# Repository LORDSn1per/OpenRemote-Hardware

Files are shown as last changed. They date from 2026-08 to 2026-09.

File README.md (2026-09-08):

# OpenRemote Rev6 Hardware

<p align="center">
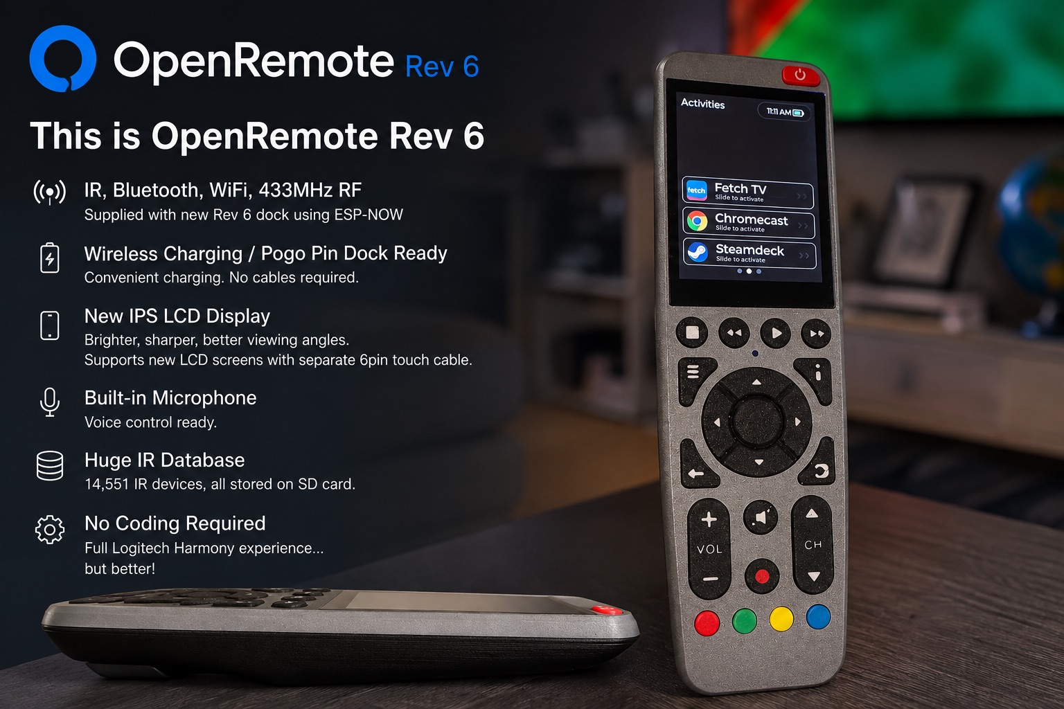
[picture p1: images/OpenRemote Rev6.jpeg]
OpenRemote Rev6 universal remote
  
</p>

OpenRemote Rev6 is an open-source, offline smart remote based on the excellent [OMOTE hardware](https://github.com/OMOTE-Community/OMOTE-Hardware). It combines a 2.8-inch capacitive touchscreen with physical buttons, infrared, Wi-Fi, Bluetooth, an ESP32-S3, expandable storage, and a fully 3D-printable enclosure.

Rev6 focuses on making the remote easier to source, nicer to print, more serviceable, and ready for dock charging—while retaining support for the original Adafruit display.

> **Firmware:** [OpenRemote Firmware](https://github.com/LORDSn1per/OpenRemote-Firmware)

## What is new in Revision 6?

- **New IPS display support.** Rev6 supports the EastRising/BuyDisplay ER-TFT028A2-4 capacitive display with a separate six-pin touch FPC. It is brighter, sharper, has much better viewing angles, is still in production, and is free of the ghost-touch problem that affected the original screen.
- **Original display compatibility.** The discontinued Adafruit Product 2770/CH280QV10-CT display remains fully supported, and the Rev6 firmware includes an option that runs it with zero ghost touches.
- **Built-in microphone.** A rear-mounted digital I2S microphone provides hardware support for voice control, voice search, and future assistant features.
- **Faster charging.** The TP4056 charging circuit is configured for up to approximately 1 A, subject to the battery, power source, and thermal conditions.
- **Dock charging input.** Rev6 includes a dedicated 5 V input before the fuse, feeding the pogo-pin charging dock contacts or any other 5 V source.
- **Improved serviceability.** Five rear-installed M3 × 8 mm screws secure the PCB and enclosure, making the remote easier to assemble and reopen.
- **Updated PCB branding.** The board is now branded OpenRemote and includes a QR code linking directly to the firmware repository.

<p align="center">
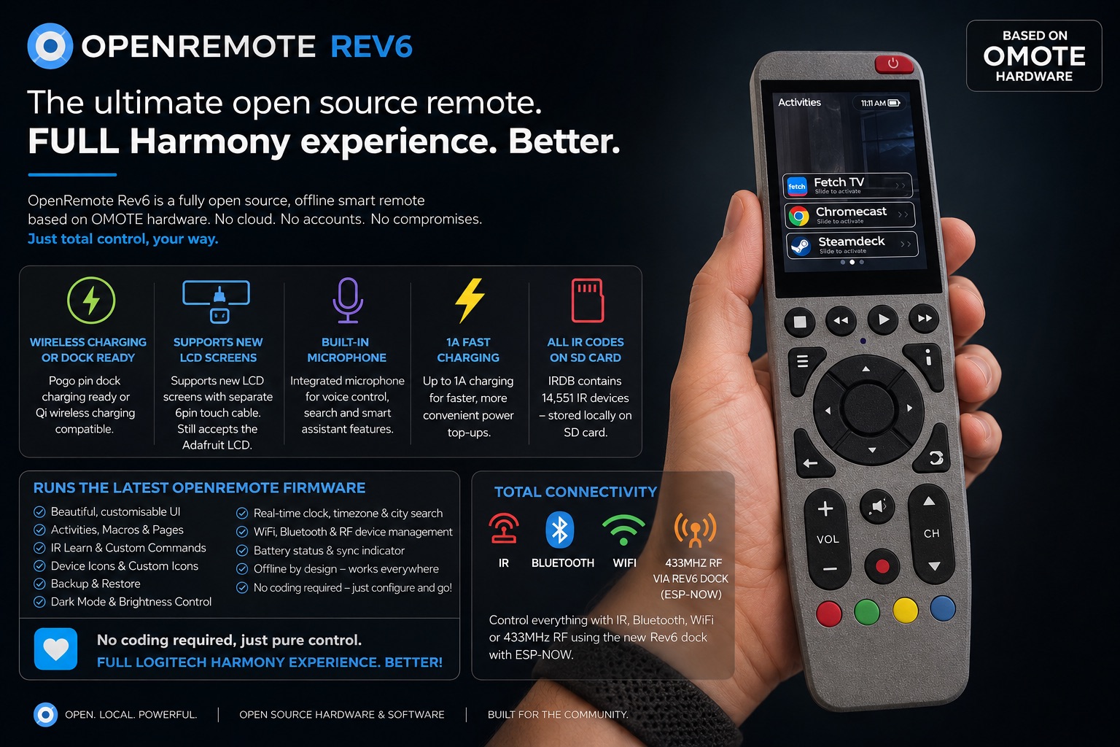
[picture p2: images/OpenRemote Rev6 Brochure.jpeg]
OpenRemote Rev6 feature overview
  
</p>

## New BuyDisplay LCD

### Why the display changed

Two things forced the move away from the original Adafruit screen:

1. **It is discontinued.** The Adafruit Product 2770 / CH280QV10-CT is no longer in production. Anyone building a remote today is hunting through dwindling stock and resellers, which is no basis for a project people are meant to be able to build.
2. **Its touch behaviour could make the remote unusable.** The Adafruit panel is subject to a well-known ghost-touch problem — phantom presses the user never made. On a remote control that is not a cosmetic annoyance: the device wakes by itself, fires commands at your equipment, and drains its own battery.

The recommended Rev6 screen is therefore the 2.8-inch 240×320 EastRising/BuyDisplay IPS TFT with capacitive touch. It is in current production, easier to source, brighter and sharper, has far better viewing angles, and does not suffer the ghost-touch fault. Its separate six-pin touch cable connects to the new J6 connector on the Rev6 PCB.

### The Adafruit display still works — with zero ghost touches

If you already own the Adafruit panel, it is not wasted. The Rev6 firmware includes an option that changes how the Adafruit touch panel is handled, and with it enabled the display produces **zero ghost touches**. It is a fully supported configuration, not a fallback, and it is why the Adafruit cover plate and matching printed parts are still published here.

Choose your display on this basis:

- **Building from scratch, or buying a screen now** — use the BuyDisplay panel. It is the current, in-production part.
- **Already have the Adafruit panel** — use it, enable the Adafruit touch option in the firmware, and print the Adafruit cover plate.

Either way, set the correct display option in the [OpenRemote firmware](https://github.com/LORDSn1per/OpenRemote-Firmware) before use.

### Fitting

The BuyDisplay assembly is approximately **0.8 mm thicker** than the original Adafruit screen. It therefore requires the newly updated BuyDisplay front cover plate. Do not try to force the thicker display into the original Adafruit cover.

Printable parts are split by display, so each folder contains a complete, matched set:

- [`CAD/BuyDisplay LCD/`](CAD/BuyDisplay%20LCD) — use **`Cover Plate 5mm (+1mm) Rev6-v37.stl`** with the new BuyDisplay screen.
- [`CAD/Adafruit LCD/`](CAD/Adafruit%20LCD) — use **`Cover Plate 4mm (+0mm) Rev6-v37.stl`** with the original Adafruit screen.

Each folder also carries a **Bambu Lab 3MF project** prepared for multicolour printing.

| BuyDisplay screen | New and original screens |
|:---:|:---:|
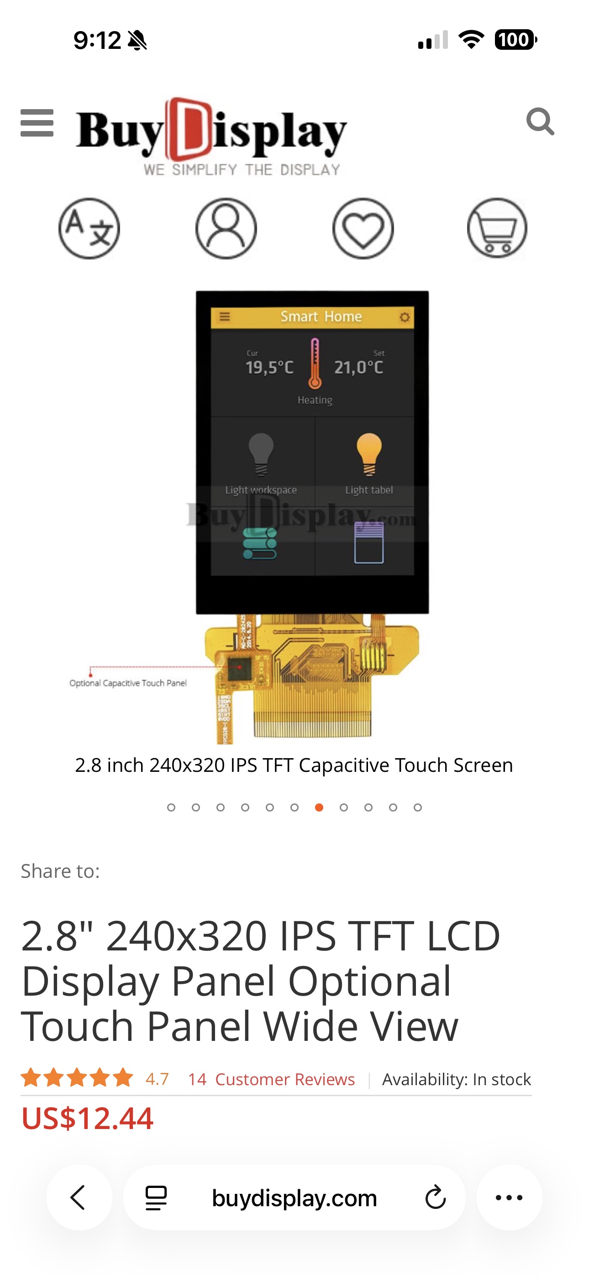
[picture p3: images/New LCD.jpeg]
BuyDisplay 2.8-inch IPS capacitive display
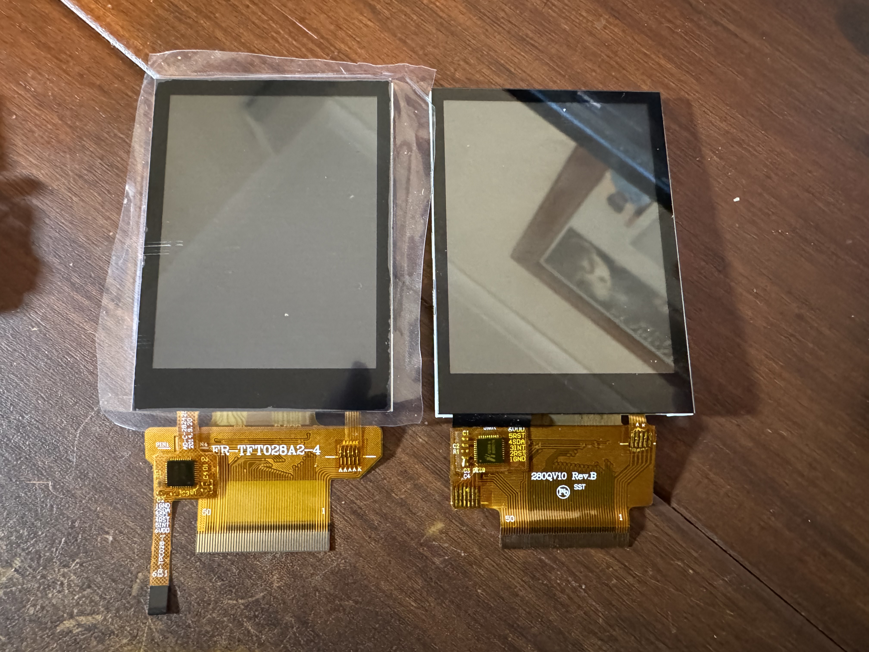
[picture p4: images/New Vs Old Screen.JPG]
BuyDisplay screen beside the original Adafruit screen
|  |  |

## Redesigned printed buttons

The Rev6 button system has been redesigned for a cleaner, more professional finish:

- The button grid now prints as **two interlocking halves** that click together.
- Separating the grid makes multicolour button graphics easier to print cleanly.
- Button faces are now completely smooth.
- The old physical cut-outs used to form button icons have been removed.
- Icons and labels can instead be printed directly into the smooth button surfaces for sharper graphics and a much nicer feel.
- The supplied Bambu Lab 3MF project contains the prepared colour-printing setup.

## Rear-case options

The Rev6 enclosure is available with two rear-shell choices:

1. **Normal rear case** — the standard shell for USB-C charging (`Case - Screws and No Pogo Pins Rev6-v37.stl`).
2. **Pogo-pin rear case** — adds two charging contacts for the self-aligning charging dock (`Case - Screws with Pogo Pins Rev6-v37.stl`).

The spring-loaded pogo pins live in the dock; the remote carries fixed gold-plated contacts, so there is nothing sprung to wear out in the handheld part.

## Charging dock

<div align="center">
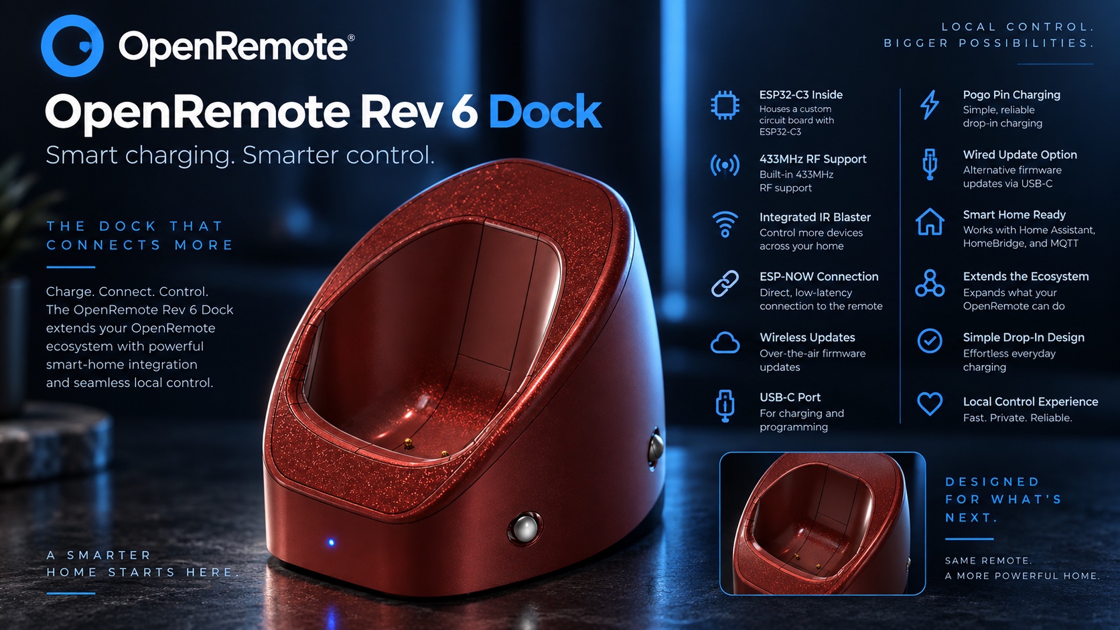
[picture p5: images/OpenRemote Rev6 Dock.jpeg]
OpenRemote Rev6 Dock feature overview
  
</div>

The Rev6 charging dock is a self-aligning cradle that charges the remote through the pogo-pin rear case, and doubles as an always-on IR and sub-GHz blaster in its own right.

- **Pogo-pin charging.** Two spring-loaded pins meet the fixed contacts in the pogo rear case, so the remote charges by being set down rather than plugged in.
- **Independent ESP32-C3.** An ESP32-C3 Super Mini gives the dock its own Wi-Fi and Bluetooth, so it can act while the remote is asleep or away from the cradle.
- **Four-emitter IR blaster.** Four MHL512IR059CRT 940 nm emitters run in parallel, each through its own 39 Ω 0.5 W resistor, switched by an FS8205A dual MOSFET. Designed for roughly 95 mA per emitter in pulsed remote-control service, giving the dock far more IR reach than the handheld unit.
- **433 MHz sub-GHz radio.** A CC1101 module on SPI adds control of RF devices that infrared cannot reach — blinds, garage doors, and similar.
- **Status LED and button.** A tactile button on GPIO3 with hardware debounce, plus a status indicator.
- **Powered by USB-C.** The dock is powered solely through the USB-C connector on the ESP32-C3 module. The 2-pin JST header (J1) is not a second power input — it carries the 5 V rail out to the pogo pins.
- **Serviceable.** A 45 × 60 mm two-layer PCB on a 37 × 52 mm M3 mounting pattern, with a separate printed base lid.
- **Smart-home relay.** Because the board has its own Wi-Fi it can hold a permanent connection to Home Assistant, an MQTT broker or Homebridge, and act on the remote's behalf while the remote sleeps. That is a firmware capability rather than a hardware one — see the [firmware repository](https://github.com/LORDSn1per/OpenRemote-Firmware) — but it is the reason the dock carries an ESP32-C3 rather than a charging circuit alone.

> **Firmware note:** the IR bank is sized for pulsed use. Firmware must not hold `IR_PWM` high continuously.

### Dock files

- Printable parts: [`CAD/Dock/STL`](CAD/Dock/STL) — dock shell, base lid, and menu button, plus a Bambu Lab 3MF project in [`CAD/Dock`](CAD/Dock).
- Fusion source: [`CAD/Charging Dock Rev6-v47.f3z`](CAD/Charging%20Dock%20Rev6-v47.f3z)
- KiCad source: [`PCB/Dock Rev6`](PCB/Dock%20Rev6) — includes its own [project README](PCB/Dock%20Rev6/README.md) covering footprints, sourcing notes, and the Fusion handoff transform.

> **Fabrication files withdrawn.** The dock's gerbers, CPL and BOM have been removed. The ESP32-C3 Super Mini footprint on the dock PCB is wrong — the 3D model is correct, but the land pattern is not — so any board made from those files would not accept the module. **Do not order a dock PCB yet.** A corrected set will be published once the footprint is fixed and the board re-verified.

## PCB files

The complete KiCad source is in [`PCB/Revision 6`](PCB/Revision%206). Custom symbols, footprints, and 3D models are included with the project.

The exact production files prepared for the Rev6 manufacturing order are here:

- [Gerber and drill ZIP](PCB/Revision%206/PCB%20Production%20Files/gerber.zip)
- [Component placement list (CPL)](PCB/Revision%206/PCB%20Production%20Files/CPL.csv)
- [Bill of materials (BOM)](PCB/Revision%206/PCB%20Production%20Files/BOM.xlsx)

The PCB is a two-layer design. The production set was exported using the **EastRising Capacitive LCD** assembly variant. The original Adafruit display remains represented in the KiCad project as an alternate variant.

> MIC1, the microphone module, does not currently have a JLCPCB/LCSC placement code in the production BOM. Source and fit it separately if your assembler cannot supply it.

## Core hardware features

- ESP32-S3 with Wi-Fi and Bluetooth
- 2.8-inch 240×320 capacitive touchscreen
- Physical navigation, media, volume, channel, activity, and colour buttons
- High-power infrared output
- MicroSD storage
- Motion-based wake support
- Built-in I2S microphone
- USB-C charging
- Pogo-pin dock charging
- Fully local operation with no mandatory cloud service

## Building the remote

1. Order the Rev6 PCB using the supplied Gerber ZIP, BOM, and CPL.
2. Source the selected LCD and use its matching front cover plate.
3. Print the enclosure and buttons. For multicolour printing, use the supplied Bambu Lab 3MF project.
4. Fit a suitable protected 3.7 V LiPo battery with the correct JST polarity.
5. Install the PCB and secure the assembly using five M3 × 8 mm screws.
6. Flash the latest [OpenRemote firmware](https://github.com/LORDSn1per/OpenRemote-Firmware).

Always verify component orientation, battery polarity, display selection, and the manufacturer preview before ordering assembled PCBs.

## Project status

The Rev6 remote PCB has been manufactured and assembled, and the first unit is running. The normal and pogo-pin rear cases and both display cover plates are complete and published.

The charging dock's enclosure parts are complete and published. Its PCB is **not ready to order**: the ESP32-C3 Super Mini footprint is being corrected, and the fabrication files have been withdrawn until that is done and verified. The KiCad source stays published so the design can be followed and reviewed.

## Credits

OpenRemote builds on the original open-source [OMOTE](https://github.com/OMOTE-Community) hardware project. Thank you to the OMOTE contributors and community for creating the foundation that made OpenRemote possible.

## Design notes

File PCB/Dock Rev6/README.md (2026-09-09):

# OpenRemote Dock Rev6 KiCad Project

This is a self-contained KiCad 10 project starter for the OpenRemote Rev6 charging dock.

## Included footprints and 3D models

| Library footprint | Intended hardware | Interface / package |
|---|---|---|
| `ESP32-C3_SuperMini_Header_2x08_P2.54mm` | ESP32-C3 Super Mini shown by the owner | Two 1x8 headers, 2.54 mm pitch; owner-supplied STEP model |
| `CC1101_433MHz_Coil_Module_2x04_P2.54mm` | 28x15 mm CC1101 433 MHz module, spring antenna version | 2x4 header, 2.54 mm pitch |
| `LED_5mm_Side_Mount_C405273` | Meihua MHL512IR059CRT IR LED, LCSC C405273 | THT, 5 mm, horizontal/side mounting |
| `FS8205A_SOT-23-6` | FUXINSEMI FS8205A, LCSC C908265 | SOT-23-6 |
| `HX-XH2.54-2PZZ_C42391660` | hanxia HX-XH2.54-2PZZ, LCSC C42391660 | Vertical shrouded 1x2 male header; vendor land pattern is 2.50 mm pitch |
| `SW_6x6x5H_THT` | 6x6 mm tactile switch, 5 mm body height | Four-pin THT |
| `LED_5mm_Green_THT` | Standard green 5 mm LED | THT, 2.54 mm pitch |

The ESP32 model is the owner's supplied `esp32 c3 supermini.step`, copied into the project as `ESP32-C3_SuperMini.step`. The project also includes `ESP32-C3_SuperMini_2x08_Header.step`: two 2.24 mm-high black 1x8 header blocks with 16 gold pins. All STEP files are project-local, so no Downloads or global KiCad 3D-model path is required.

## Important sourcing notes

- The ESP module follows the owner's supplied **16-pin ESP32-C3 Super Mini** image: 18x22.52 mm with two 1x8, 2.54 mm header rows. It does not use the different 18-pin Waveshare C3-Zero footprint from the earlier retail link.
- J1 is the exact hanxia HX-XH2.54-2PZZ sold as LCSC C42391660. LCSC describes it as 2.54 mm, but its manufacturer-linked EasyEDA land pattern uses 2.50 mm pad pitch, 1.0 mm drills, and a 7.5 x 5.9 mm shrouded body; the project follows that land pattern.
- CC1101 clone modules vary. This footprint follows the common 28x15 mm, 2x4 2.54 mm module and the pin order shown in the provided image. Check the delivered module before ordering the PCB.
- `Dock Rev6.kicad_pcb` uses a 45x60 mm main body with narrow front and rear tongues. The confirmed physical rear tongue ends at dock Z=`-68.0 mm`; it is straight between the two rear receivers and has no obsolete scallops.
- The owner confirmed that the provisional handoff reversed the physical faces. The installed-board mapping is now **physical dock Z = KiCad Y - 140 mm**: Fusion Z=`-70` is the rear and Z=`+30` is the front.
- U1 is centred at KiCad `(100.00, 82.39)` with USB-C facing the physical rear and is placed on `B.Cu`. The ESP32 module hangs below the host PCB; the black header plastic lies between the ESP32 board and the host PCB, as it will when assembled with female header sockets. It was moved 1.5 mm into the cavity so the module PCB clears the rear wall. Its exact 18 mm body has approximately 0.50 mm lateral clearance to each physical rear lid receiver.
- The four large `User.Drawings` circles are the exact **15 mm OD physical receiver outlines**, mirrored into the confirmed board coordinates. Rear centres are KiCad `(82.998, 80.858)` and `(117.002, 80.858)`; front centres are `(83.643, 161.292)` and `(116.357, 161.292)`.
- In Fusion, `Dock + Correct Rear USB-C Opening Base Feature` was removed and the retained master body was restored as the visible solid `Dock - User Editable Shell (No Cutouts)`. This leaves the enclosure apertures for the owner to sketch and cut directly without deleting the dock shell.
- The final exact-solid Fusion audit reports **no collision between the underside ESP32/header assembly and the base lid or its bosses**. The lowest point of the ESP32 model is 0.294 mm above the flat lid surface. The USB, button, and LED apertures are intentionally left for the owner to create before enclosure release.
- Four 3.3 mm NPTH M3 mounting holes are on an exact 37x52 mm pattern at dock X/Z `(+/-18.5, +6)` and `(+/-18.5, -46)`. Each hole has an R4 mm all-copper keepout. H1-H4 are locked `board_only` footprints, excluded from BOM and position files, so **Update PCB from Schematic will not delete them again**.
- The matching Fusion base lid has four 7.5 mm OD bosses at those same centres. Each boss has a 2.55 mm blind pilot, an 8.0 mm PCB seating plane, and 3.4 mm thread engagement for an M3x5 screw through this 1.6 mm board. The original pre-boss lid body is retained hidden for rollback.

## Pin order

CC1101 pads are numbered by rows as shown in the supplied diagram: `1 GND`, `2 VCC`, `3 GDO0`, `4 CSN`, `5 SCK`, `6 MOSI`, `7 MISO/GDO1`, `8 GDO2`.

ESP32-C3 Super Mini pad numbers use the printed signal names directly. USB-C is at the top: left row `5V`, `GND`, `3V3`, `GPIO4/SCK/A4`, `GPIO3/A3`, `GPIO2/A2`, `GPIO1/A1`, `GPIO0/A0`; right row `GPIO5/MISO/A5`, `GPIO6/MOSI`, `GPIO7/SS`, `GPIO8/SDA`, `GPIO9/SCL`, `GPIO10`, `GPIO20/RX`, `GPIO21/TX`.

## Electrical design

- CC1101 SPI: `GPIO4 SCK`, `GPIO5 MISO`, `GPIO6 MOSI`, `GPIO7 CSN`; interrupts are `GPIO10 GDO0` and `GPIO20 GDO2`.
- Four MHL512IR059CRT emitters are connected in parallel through individual `39R 0.5W` resistors. GPIO0 drives both paralleled halves of Q1 through `100R`, with a `100k` gate pulldown.
- The 39R IR branches are designed for pulsed remote-control service at approximately 95mA per LED from 5V. Firmware must not hold `IR_PWM` high continuously.
- The green status LED uses GPIO1 and `1k`. The tactile button uses GPIO3 with a `10k` pull-up and `100nF` hardware debounce.
- ESP32-C3 strap pins GPIO2, GPIO8, and GPIO9 are deliberately left unconnected; GPIO21 is also reserved.
- Added decoupling: `100nF + 10uF` at the ESP 5V input, `100nF + 10uF` at the CC1101 3.3V rail, and `100uF + 100nF` at the pulsed IR bank.

### Pogo-pin output protection

`F1` is a 1 A resettable polyfuse (PPTC, LCSC C220146,
`DockRev6:Fuse_1206_3216Metric_Pad1.42x1.75mm_HandSolder`) in series between the `+5V`
rail and `J1` pin 1, creating the `POGO_5V` net. It is the same part the remote uses as
its F1. The IR bank, the ESP32 and the decoupling all stay on the raw `+5V` rail; only
the pogo output passes through the fuse.

**It is in the schematic only — it is not yet placed or routed on the PCB.**

This replaced an earlier BAT20J series diode, for two reasons. A polyfuse actually
addresses the failure being guarded against: if the exposed pogo contacts are shorted,
it heats and trips, where a series diode would simply conduct and let the rail collapse.
And it barely drops any voltage — a few tens of millivolts against roughly 0.45 V for a
Schottky at 1 A — so the remote still sees close to a full 5 V.

Two things to be aware of:

- A polyfuse does **not** block reverse current. The dropped diode would have stopped
  the remote back-feeding into the dock; the fuse does not. If back-feed matters, an
  ideal-diode controller or a load switch would cover both cases.
- Trip is thermal, so it takes seconds rather than being instant, and hold current
  derates as temperature rises. With the remote's TP4056 set near 1 A, a 1 A hold part
  sits close to its limit inside a closed enclosure. Watch for nuisance trips during a
  full-rate charge; a 1.1 A or 1.5 A hold part is the fallback.

### Capacitor placement

- `C1 100nF`: immediately beside U1's 5V/GND header pins; shortest possible loop.
- `C2 10uF`: beside U1 and C1 on the 5V rail; C1 should be closer than C2.
- `C3 100nF`: immediately beside U2 pins 2 VCC and 1 GND; this is the most placement-sensitive radio capacitor.
- `C4 10uF`: beside U2 and C3; C3 should be closer than C4.
- `C5 100nF`: beside U1 GPIO3 and pull-up R1, at the controller end of the BUTTON trace.
- `C6 100uF`: beside Q1/J1 at the high-current IR power entry/current loop.
- `C7 100nF`: beside Q1/J1 and C6, with the shortest 5V-to-GND loop; C7 should be closer to the switching loop than C6.

`Dock Rev6.kicad_pcb` is populated but not routed. The remaining SMD parts are staged by circuit: C1/C2 beside the header-mounted ESP32, C5/R1 immediately left of it, C3/C4 beside the CC1101 power pins, R3/R4/Q1 to the left of the CC1101 coil envelope, C7 beside J1, and R2 beside D5. The current DRC reports silkscreen cleanup warnings plus the expected unrouted nets; it does not report a copper short, hole, or board-edge clearance failure.

The `.before-*` rollback boards, the DRC/ERC reports, the netlist and the exported schematic PDF have been removed; only the current `Dock Rev6.kicad_pcb` and `Dock Rev6.kicad_sch` are kept. Earlier states remain in git history if a rollback is ever needed. `apply_mechanical_fit_v3.py` reapplies the final U1 position and rear-tongue geometry without altering nets or component identities. Use KiCad's native refill after running it. Do not run `generate_dock_rev6_mechanical_board.py` on the populated board; that generator creates a blank mechanical PCB and would replace component placement.

## Fusion 3D handoff

`Dock Rev6 PCB Assembly.step` is the current board-plus-components model handed to
Fusion. Regenerate it with `export_dock_rev6_step.py`, which runs:

```
kicad-cli pcb export step --subst-models --no-dnp --force
```

No origin flag is passed, so the STEP keeps KiCad's absolute board coordinates
(substrate spans X `77.5`-`122.5`, Y `-166.0`-`-72.0`, Z `0`-`1.6`). The Fusion
placement transform depends on that:

```
dock X =  step X - 100 mm
dock Y =  step Z + 8 mm      (PCB seating plane on the base-lid bosses)
dock Z = -step Y - 140 mm    (owner-confirmed mirrored physical face)
```

`CAD/FusionScripts/DockRev6PCBReplace` deletes any existing `Dock Rev6 PCB*`
occurrence, re-imports this STEP at that transform as the component
`Dock Rev6 PCB`, then re-runs the solid interference check against `Dock:1` and
`Dock Base Lid:1` and writes `CAD/Dock Rev6/Charging Dock Rev6 PCB Replace Report.json`.
Base-lid interference is a failure; dock-shell interference at SW1, J1, D1-D5 is
expected until the owner cuts the USB, button, and LED apertures.

`Dock Rev6 Component Staging.step` is the superseded 26 Aug 16:52 export, taken
before power/ground routing was finalised and before SW1 moved to the
`SW-TH_KH-6X6X5H-ZJ` (C2837541) model and J1 to `HX-XH2.54-2PZZ` (C42391660). It
is kept only for rollback; Fusion should no longer import it.

`Dock Rev6 PCB Assembly Preview.png` and `Dock Rev6 PCB Assembly Preview Bottom.png`
are `kicad-cli pcb render` views of the same board state.

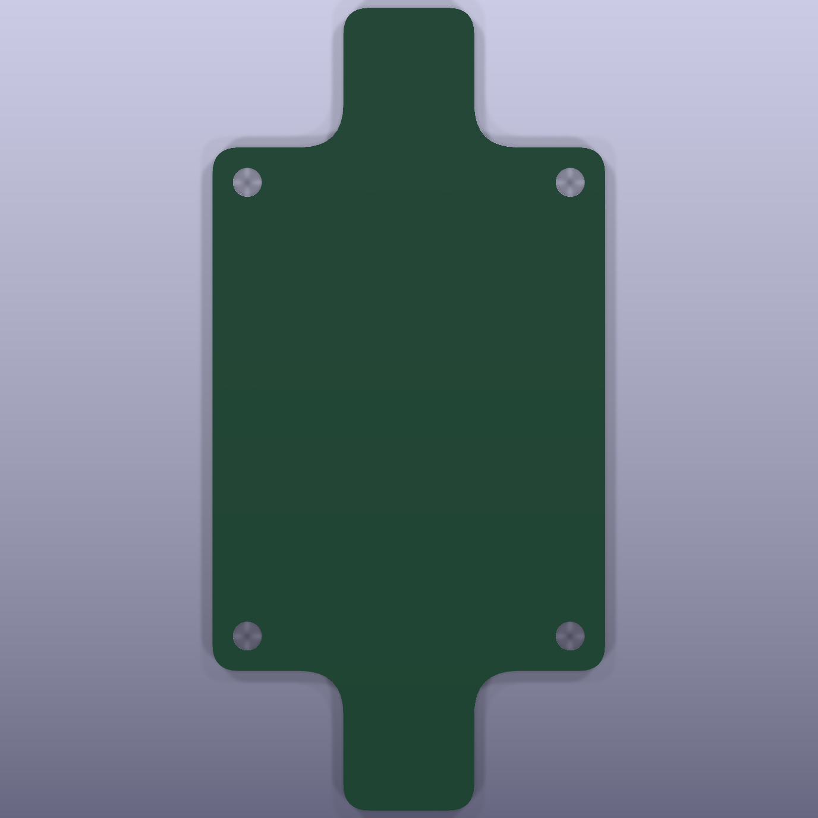
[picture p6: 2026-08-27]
PCB/Dock Rev6/Dock Rev6 PCB Mechanical Preview.png

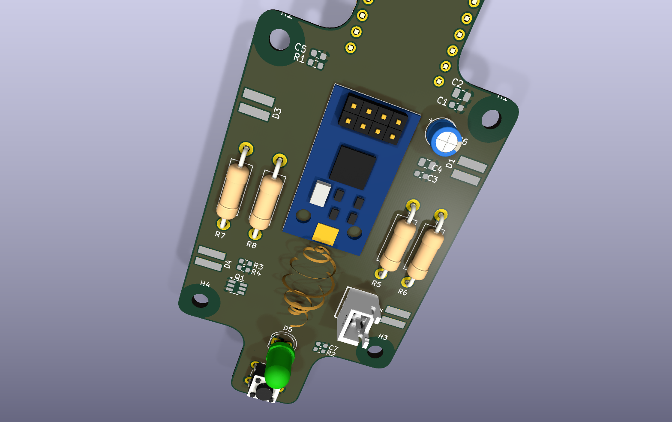
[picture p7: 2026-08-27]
PCB/Dock Rev6/Dock Rev6 J1 C42391660 Preview.png

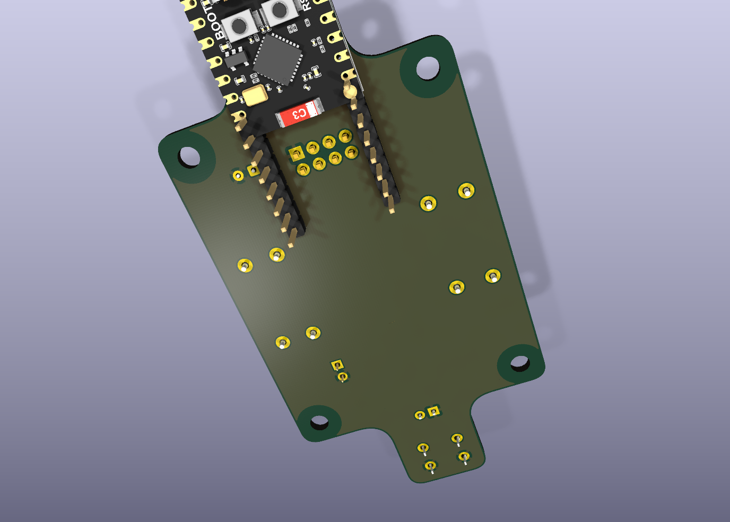
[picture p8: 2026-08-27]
PCB/Dock Rev6/Dock Rev6 Bottom ESP32 Preview.png

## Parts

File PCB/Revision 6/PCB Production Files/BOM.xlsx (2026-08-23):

Designator | Value | Footprint | LCSC Part #
C1,C9,C10,C12,C17,C20,C22,C23,C24,C26,C29 | 100nF | C_0603_1608Metric | C1591
C2,C4,C15 | 1uF | C_0603_1608Metric | C15849
C3,C5,C6,C7,C8,C11,C13,C16,C18,C21,C25,C28 | 10uF | C_0805_2012Metric | C15850
D1 | BAT20J | D_SOD-323 | C49238173
D2 | SFH4547 | LED_5mm_Side_Mount | C405273
D3,D4,D5 | LED | LED_0603_1608Metric | C965807
D6,D7,D8,D9,D10,D11,D12,D13,D14,D15,D16 | LED | LED_0603_1608Metric | C84265
F1 | 1000mA | Fuse_1206_3216Metric_Pad1.42x1.75mm_HandSolder | C220146
J1 | USB_C_Receptacle_USB2.0 | USB_C_Receptacle_HRO_TYPE-C-31-M-12 | C2982555
J2 | Conn_01x50 | TFT_2.83IN_240X320_50PIN | C11098
J3,J7 | JST_PH_B2B-PH | JST_PH_B2B-PH-SM4-TB_1x02-1MP_P2.00mm_Vertical | C160352
J5 | Micro_SD_Card | MicroSD Slot TF-01A | C20613191
J6 | ER-CON06HB-1_TOUCH | ER-CON06HB-1_Compatible_1x06_P0.50mm_BottomContact | C202118
Q1,Q3,Q4,Q5,Q7 | DMG2301L | SOT-23 | C102619
Q2 | MBT3904DW1 | SOT-363_SC-70-6 | C110150
Q6 | FS8205A | SOT-23-6 | C908265
R1,R5,R23,R31,R32,R33,R34,R35,R38,R39,R40,R41,R42,R43,R44 | 2k2 | R_0603_1608Metric | C114662
R2,R3,R27,R28,R29 | 1k | R_0603_1608Metric | C22548
R4 | 100 | R_0603_1608Metric | C125923
R6,R10,R13,R14,R19,R20,R22,R24,R25,R26,R30,R36,R37 | 10k | R_0603_1608Metric | C98220
R7,R9 | 5.1k | R_0603_1608Metric | C105580
R8 | 1K2 | R_0603_1608Metric | C22765
R11,R12 | 4k7 | R_0603_1608Metric | C99782
R15,R16,R17,R18 | 10 | R_0603_1608Metric | C109318
R21 | 3R3 | R_0805_2012Metric | C313912
R45,R46,R47 | 4k7 | R_0603_1608Metric | C23162
S1,S2,S3,S4,S5,S6,S7,S8,S9,S10,S11,S12,S13,S14,S15,S16,S17,S18,S19,S20,S22,S23,S24,S25,S26 | TL3342F160QG | SW_SPST_TL3342 | C778172
U1 | DW01A | SOT-23-6 | C18164398
U2 | XC6220B331 | SOT-23-5 | C86534
U3 | CH340C | SOIC-16_3.9x9.9mm_P1.27mm | C84681
U4 | USBLC6-2P6 | SOT-666 | C2827693
U5 | LIS3DHTR | XDCR_LIS3DHTR | C15134
U6 | TSSP77038 | Heimdall vertical | C3291489
U7 | ESP32-S3-WROOM-1-N16R8 | ESP32-S3-WROOM-1 | C2913202
U8 | AP2112K-3.3 | SOT-23-5 | C51118
U9 | MAX17048G | TDFN-8-1EP_2x2mm_P0.5mm_EP0.8x1.2mm | C2682616
U11 | TP4056 | Infineon_PG-DSO-8-27_3.9x4.9mm_EP2.65x3mm | C725790
U12 | TCA8418 | HVQFN-24-1EP_4x4mm_P0.5mm_EP2.5x2.5mm | C138713

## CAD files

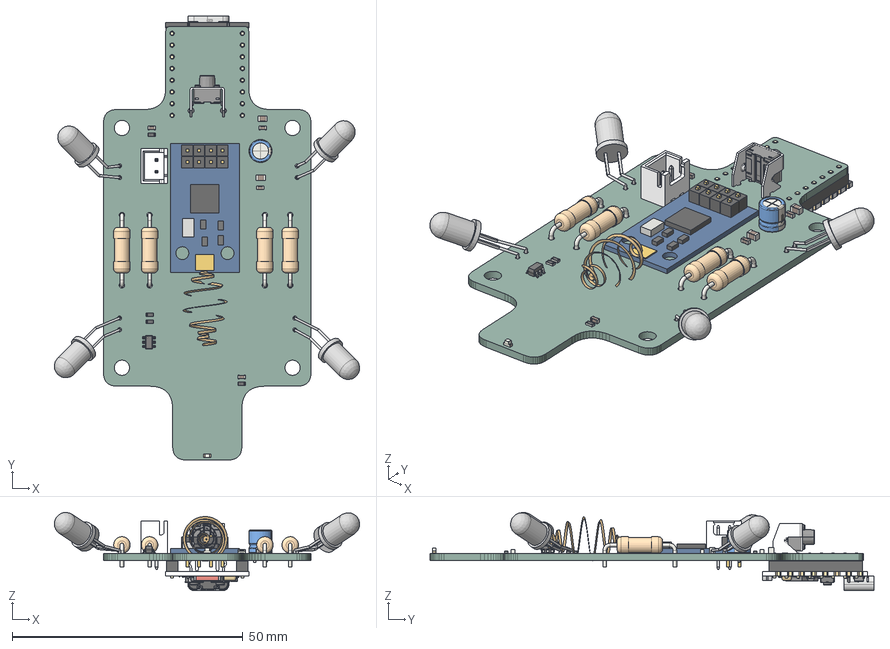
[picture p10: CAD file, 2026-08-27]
PCB/Dock Rev6/Dock Rev6 PCB Assembly.step
66.2 x 96.3 x 16.9 mm
R_Axial_DIN0411_L99mm_D36mm_P1524mm_Horizontal x 4
R_0603_1608Metric x 4
C_0603_1608Metric x 4
SOT-23-6
LED_0603_1608Metric
KiCad IR LED Assembly - 25deg 3mm
C_0805_2012Metric x 2
CP_Radial_D50mm_P250mm
CONN-TH_2P-P2.50_HX-2.54MM-2P-ZZ-MS
PCB
CC1101
Crystal
RF component 0
RF component 1
RF component 2
RF component 3
Header pin 0 -1.27
Header body 0 -1.27
Header pin 0 1.27
Header body 0 1.27
Header pin 1 -1.27
Header body 1 -1.27
Header pin 1 1.27
Header body 1 1.27
Header pin 2 -1.27
Header body 2 -1.27
Header pin 2 1.27
Header body 2 1.27
Header pin 3 -1.27
Header body 3 -1.27
Header pin 3 1.27
Header body 3 1.27
Antenna pad
433MHz spring antenna
usb4215-03-a_1
RES0201 v1 x 11
C0201 v4 x 10
C0402 v1 x 4
Cathode
Anode
Cathode Bar
QFN-32 V6 v2
switch 3x4x2mm - 2 Pad v2 x 2
TEMP ESP32-C3 2x08 Header Export
Dock Rev6_PCB

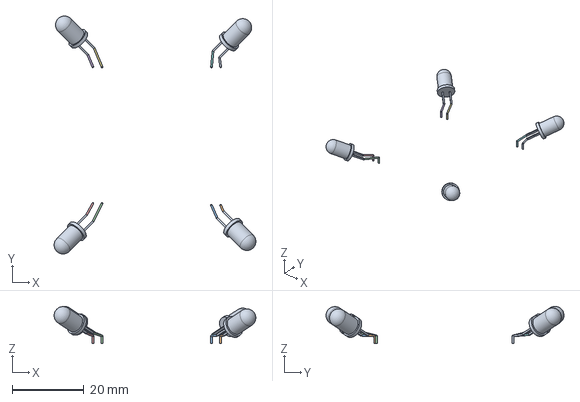
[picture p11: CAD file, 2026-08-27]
PCB/Dock Rev6/project_libraries/3D-models/Dock_IR_LED_Assembly_25deg_3mm.step
56.1 x 66.2 x 10.4 mm

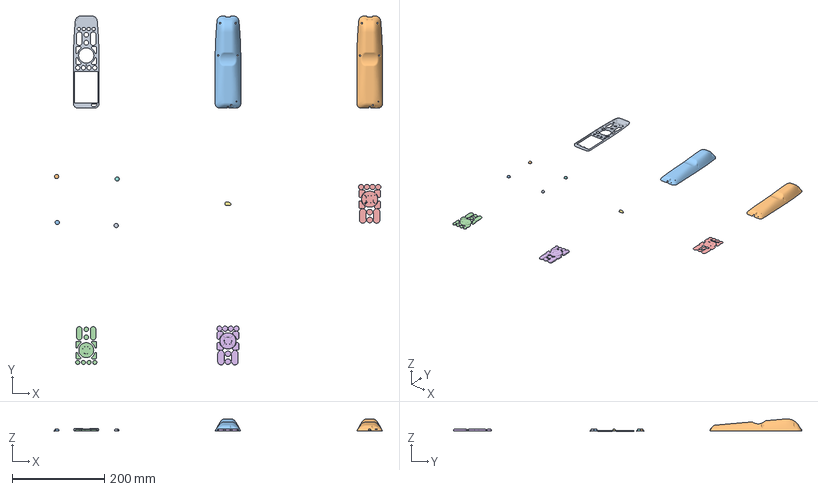
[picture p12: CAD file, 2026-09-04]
CAD/Adafruit LCD/OpenRemote Rev6 - Adafruit LCD.3mf
711.3 x 756.5 x 26.5 mm
Cover Plate 4mm (+0mm) Rev6-v37.stl
Case - Screws with Pogo Pins Rev6 v40.stl
Case - Screws and No Pogo Pins Rev6 v40.stl
Button Grid Adafruit Rev6-v37.stl_A
Button Grid Adafruit Rev6-v37.stl_B
Button Grid Adafruit Rev6-v37.stl
Off Button Adafruit Rev6-v37.stl
Colour Button Adafruit Rev6-v37.stl x 4

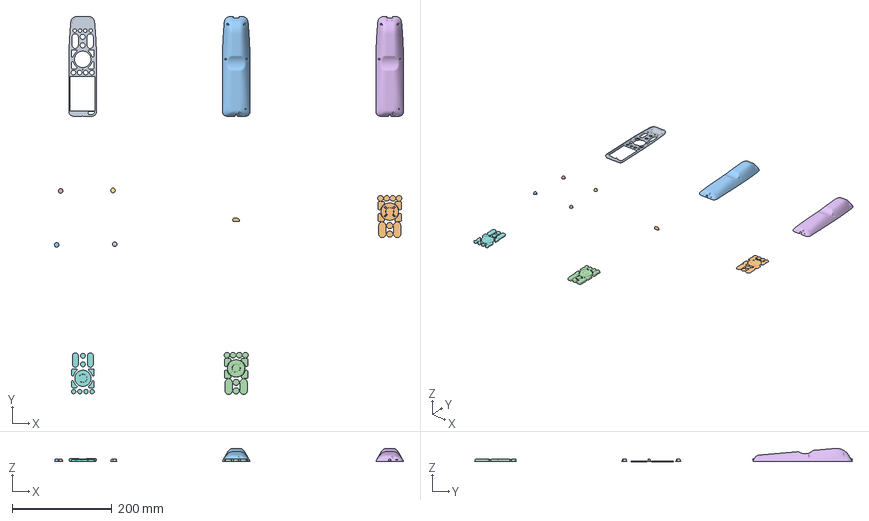
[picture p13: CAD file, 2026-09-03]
CAD/BuyDisplay LCD/OpenRemote Rev6 - BuyDisplay LCD.3mf
699.0 x 756.5 x 26.5 mm
Cover Plate 5mm (+1mm) Rev6-v37.stl
Off Button BuyDisplay Rev6-v37.stl
Colour Button BuyDisplay Rev6-v37.stl x 4
Button Grid BuyDisplay Rev6-v37.stl
Case - Screws with Pogo Pins Rev6-v37.stl
Button Grid - Flat.stl_A
Button Grid - Flat.stl_B
Case - Screws and No Pogo Pins Rev6-v37.stl

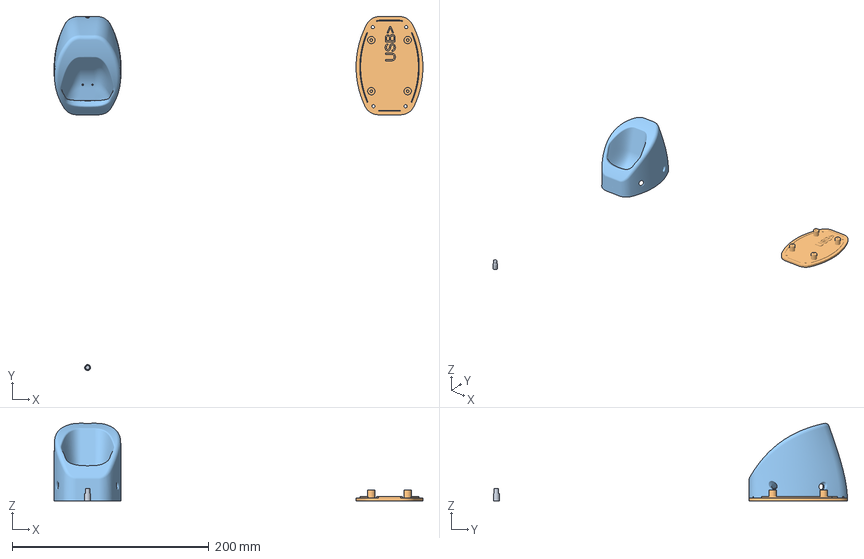
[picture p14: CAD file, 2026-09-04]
CAD/Dock/OpenRemote Dock Rev6.3mf
375.3 x 360.2 x 78.9 mm
Dock Menu Button Rev6-v47.stl
Dock Base Lid Rev6 v51.stl
Dock Rev6 v51.stl

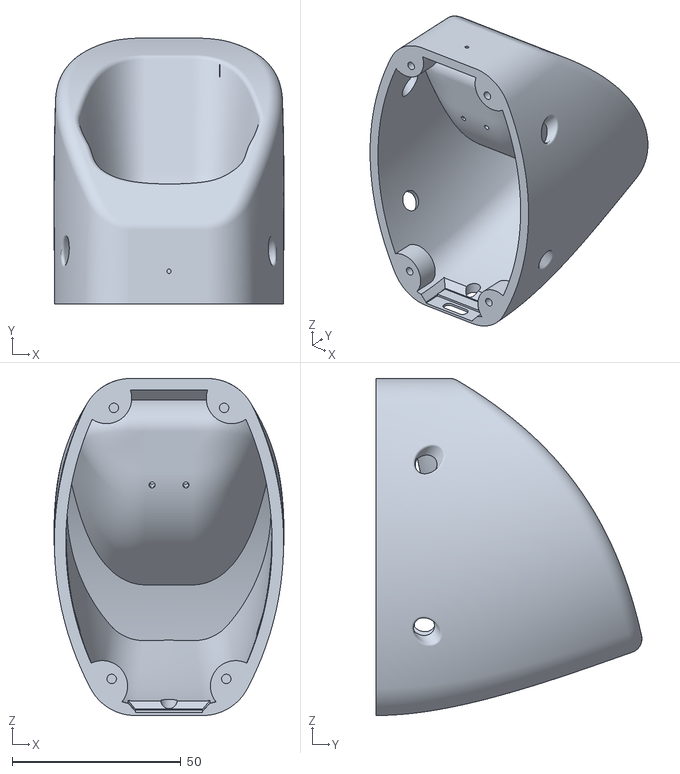
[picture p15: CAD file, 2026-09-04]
CAD/Dock/STL/Dock Rev6 v51.stl
68.2 x 78.9 x 100.0

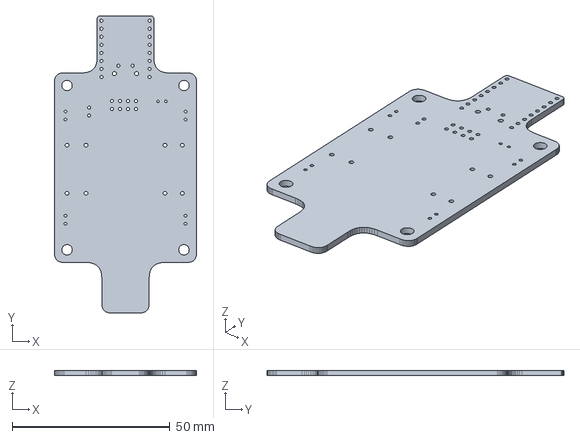
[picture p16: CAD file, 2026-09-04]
CAD/Hardware Models/Dock Rev6 PCB - Board Only.step
45.0 x 94.0 x 1.60 mm

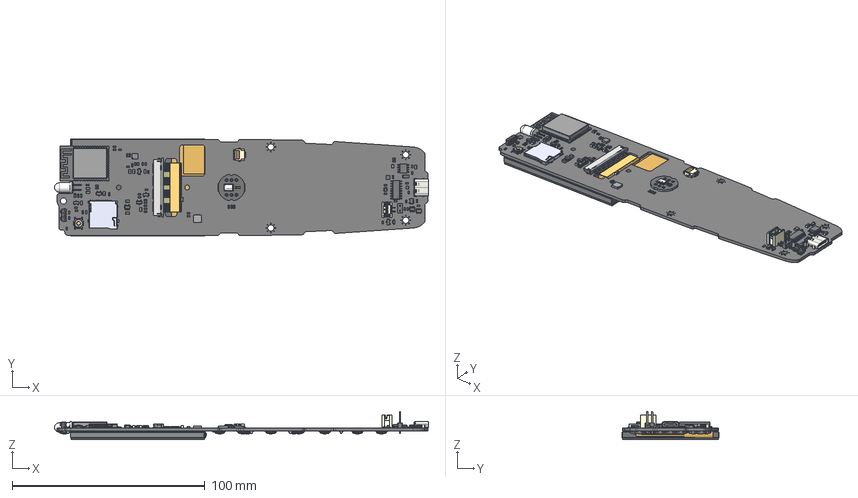
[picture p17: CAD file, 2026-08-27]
CAD/PCB Imports/OpenRemote Rev6 PCB.step
194.0 x 50.2 x 14.5 mm
Side Mount LED v1
R_0603_1608Metric x 46
D_SOD-323
B2B-PH-SM4-TB(LF)(SN)
PowerIntegrations_SO-8
C_0603_1608Metric x 15
SOT-23-5 x 2
C_0805_2012Metric x 13
SOT-23 x 6
LIS3DH
LED_0603_1608Metric x 14
SOT-363_SC-70-6
0603 Resistor v1
ESP32-S3-WROOM-1
Fuse_1206_3216Metric
SOT-23-6 x 2
(Nicht gespeichert)
SOIC-16_3.9x9.9mm_P1.27mm
(Unsaved)
DFN-8_2x2mm_Pitch0.5mm
TF-01A_TF-01A
SOT_666
PinHeader_1x02_P254mm_Vertical
lock
pins
280QV10 v5
HVQFN_24_1EP_4x4mm_P05mm_EP21x21mm
SW_SPST_TL3342 x 25
R_0805_2012Metric
USB_C_Receptacle_16P_TopMnt_Horizontal_GCT_USB4105-xx-A
display_front_00_part
display_front_01_part
display_front_02_part
display_front_03_part
display_front_04_part
display_front_05_part
display_front_06_part
display_front_07_part
screen_label_0_0_1_part
screen_label_0_0_2_part
screen_label_0_0_3_part
screen_label_0_1_0_part
screen_label_0_2_0_part
screen_label_0_3_1_part
screen_label_0_3_2_part
screen_label_0_3_3_part
screen_label_0_4_4_part
screen_label_0_5_4_part
screen_label_0_6_0_part
screen_label_0_6_1_part
screen_label_0_6_2_part
screen_label_0_6_3_part
screen_label_1_0_1_part
screen_label_1_0_2_part
screen_label_1_0_3_part
screen_label_1_0_4_part
screen_label_1_1_0_part
screen_label_1_2_0_part
screen_label_1_3_0_part
screen_label_1_4_0_part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

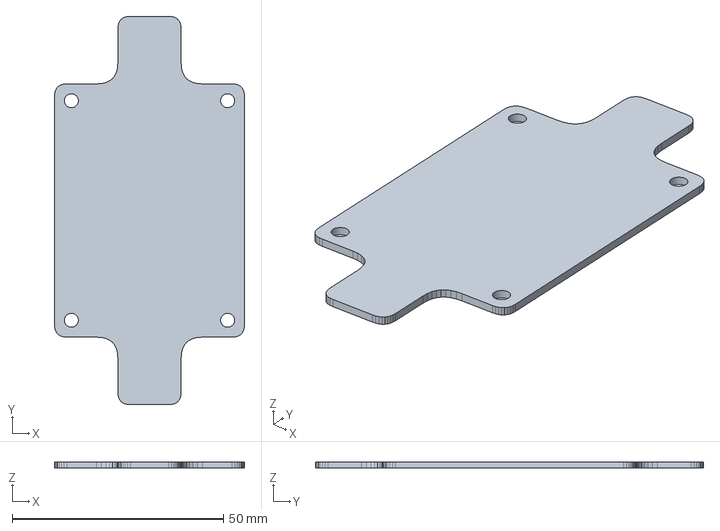
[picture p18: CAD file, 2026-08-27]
PCB/Dock Rev6/Dock Rev6 Mechanical PCB.step
45.0 x 92.0 x 1.51 mm

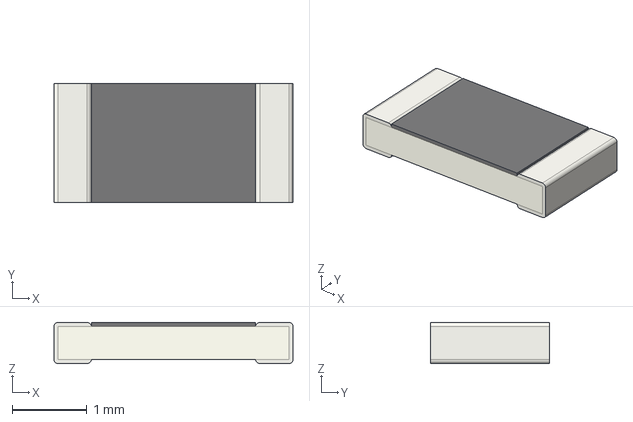
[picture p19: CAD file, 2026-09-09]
PCB/Dock Rev6/project_libraries/3D-models/Fuse_1206_3216Metric.step
3.20 x 1.60 x 0.55 mm

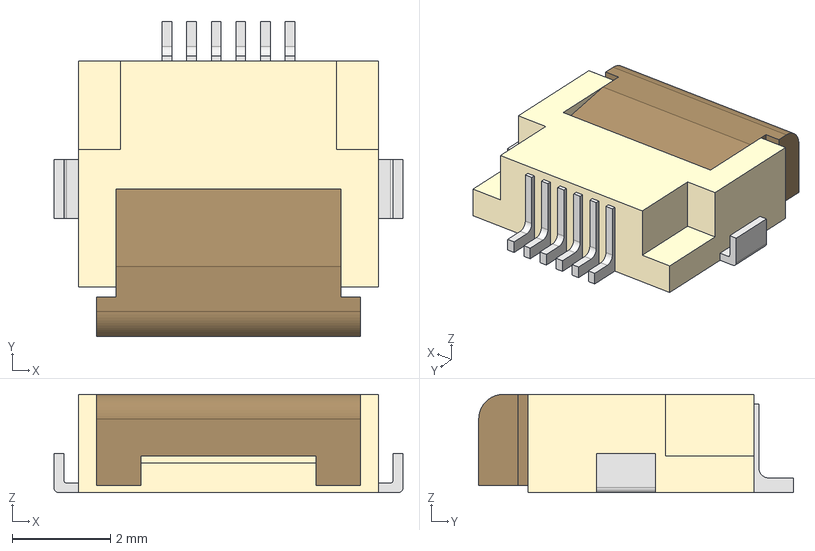
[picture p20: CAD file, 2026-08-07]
PCB/Revision 6/project_libraries/3D-models/Hirose_FH12-6S-0.5SH_1x06_P0.50mm.step
7.10 x 6.40 x 2.00 mm
lock
pins

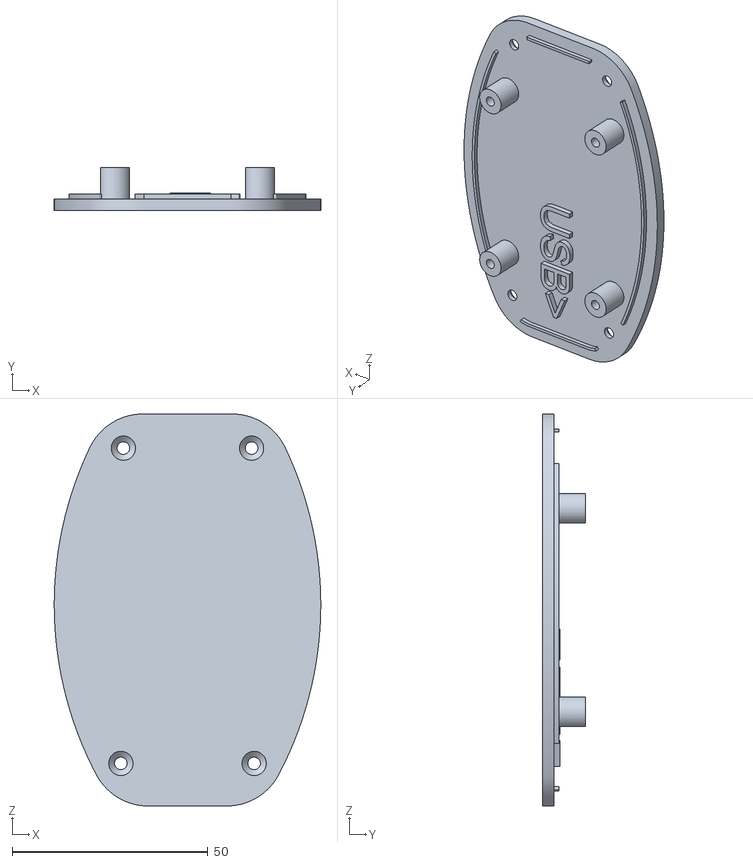
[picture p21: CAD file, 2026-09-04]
CAD/Dock/STL/Dock Base Lid Rev6 v51.stl
68.0 x 11.0 x 100.0

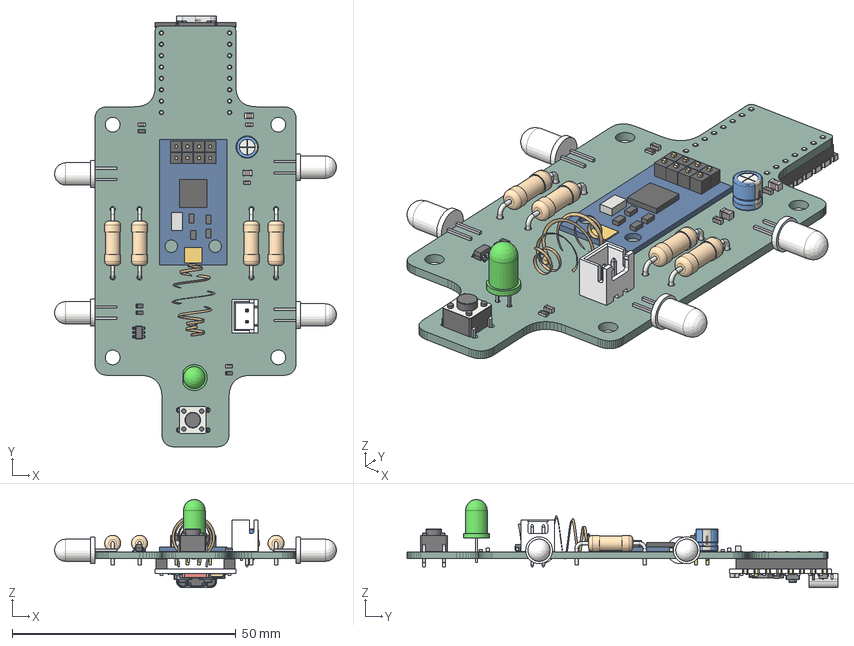
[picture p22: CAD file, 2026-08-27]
PCB/Dock Rev6/Dock Rev6 Component Staging.step
63.0 x 96.3 x 19.7 mm
R_Axial_DIN0411_L99mm_D36mm_P1524mm_Horizontal x 4
SW_PUSH_6mm_h5mm
Side Mount LED v1 x 4
R_0603_1608Metric x 4
C_0603_1608Metric x 4
SOT-23-6
C_0805_2012Metric x 2
LED_D5.0mm
CP_Radial_D50mm_P250mm
CONN-TH_2P-P2.50_HX-2.54MM-2P-ZZ-MS
PCB
CC1101
Crystal
RF component 0
RF component 1
RF component 2
RF component 3
Header pin 0 -1.27
Header body 0 -1.27
Header pin 0 1.27
Header body 0 1.27
Header pin 1 -1.27
Header body 1 -1.27
Header pin 1 1.27
Header body 1 1.27
Header pin 2 -1.27
Header body 2 -1.27
Header pin 2 1.27
Header body 2 1.27
Header pin 3 -1.27
Header body 3 -1.27
Header pin 3 1.27
Header body 3 1.27
Antenna pad
433MHz spring antenna
usb4215-03-a_1
RES0201 v1 x 11
C0201 v4 x 10
C0402 v1 x 4
Cathode
Anode
Cathode Bar
QFN-32 V6 v2
switch 3x4x2mm - 2 Pad v2 x 2
TEMP ESP32-C3 2x08 Header Export
Dock Rev6_PCB

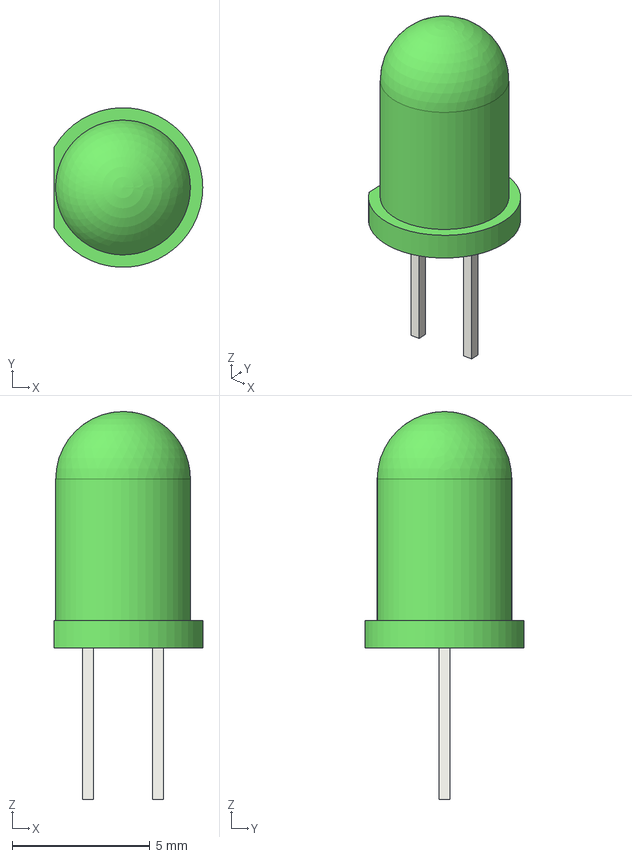
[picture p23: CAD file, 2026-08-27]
PCB/Dock Rev6/project_libraries/3D-models/LED_5mm_Green.step
5.40 x 5.79 x 14.1 mm

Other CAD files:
PCB/Revision 6/project_libraries/3D-models/ER-TFT028-4.2.step
CAD/Adafruit LCD/STL/Off Button Adafruit Rev6-v37.stl
CAD/BuyDisplay LCD/STL/Off Button BuyDisplay Rev6-v37.stl
CAD/Dock/STL/Dock Menu Button Rev6-v47.stl
CAD/Adafruit LCD/STL/Button Grid Adafruit Rev6-v37.stl
CAD/Adafruit LCD/STL/Case - Screws and No Pogo Pins Rev6 v40.stl
CAD/Adafruit LCD/STL/Case - Screws with Pogo Pins Rev6 v40.stl
CAD/Adafruit LCD/STL/Colour Button Adafruit Rev6-v37.stl
CAD/Adafruit LCD/STL/Cover Plate 4mm (+0mm) Rev6-v37.stl
CAD/BuyDisplay LCD/STL/Button Grid BuyDisplay Rev6-v37.stl
CAD/BuyDisplay LCD/STL/Case - Screws and No Pogo Pins Rev6 v40.stl
CAD/BuyDisplay LCD/STL/Case - Screws with Pogo Pins Rev6 v40.stl
CAD/BuyDisplay LCD/STL/Case - Screws with Pogo Pins Rev6-v37.stl
CAD/BuyDisplay LCD/STL/Colour Button BuyDisplay Rev6-v37.stl
CAD/BuyDisplay LCD/STL/Cover Plate 5mm (+1mm) Rev6-v37.stl
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

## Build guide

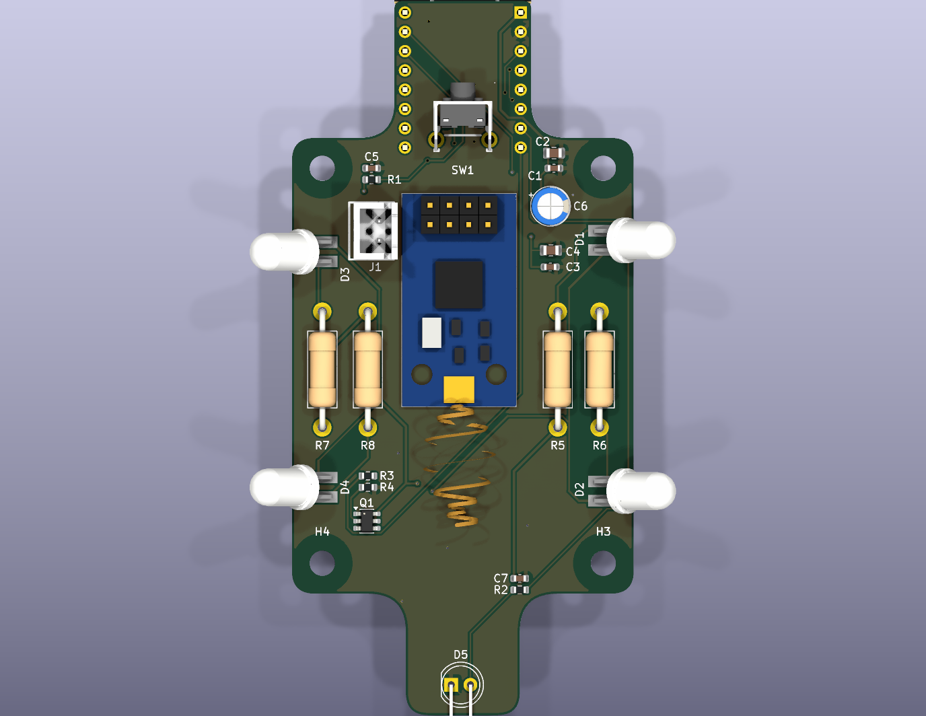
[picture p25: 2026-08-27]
PCB/Dock Rev6/Dock Rev6 PCB Assembly Preview.png

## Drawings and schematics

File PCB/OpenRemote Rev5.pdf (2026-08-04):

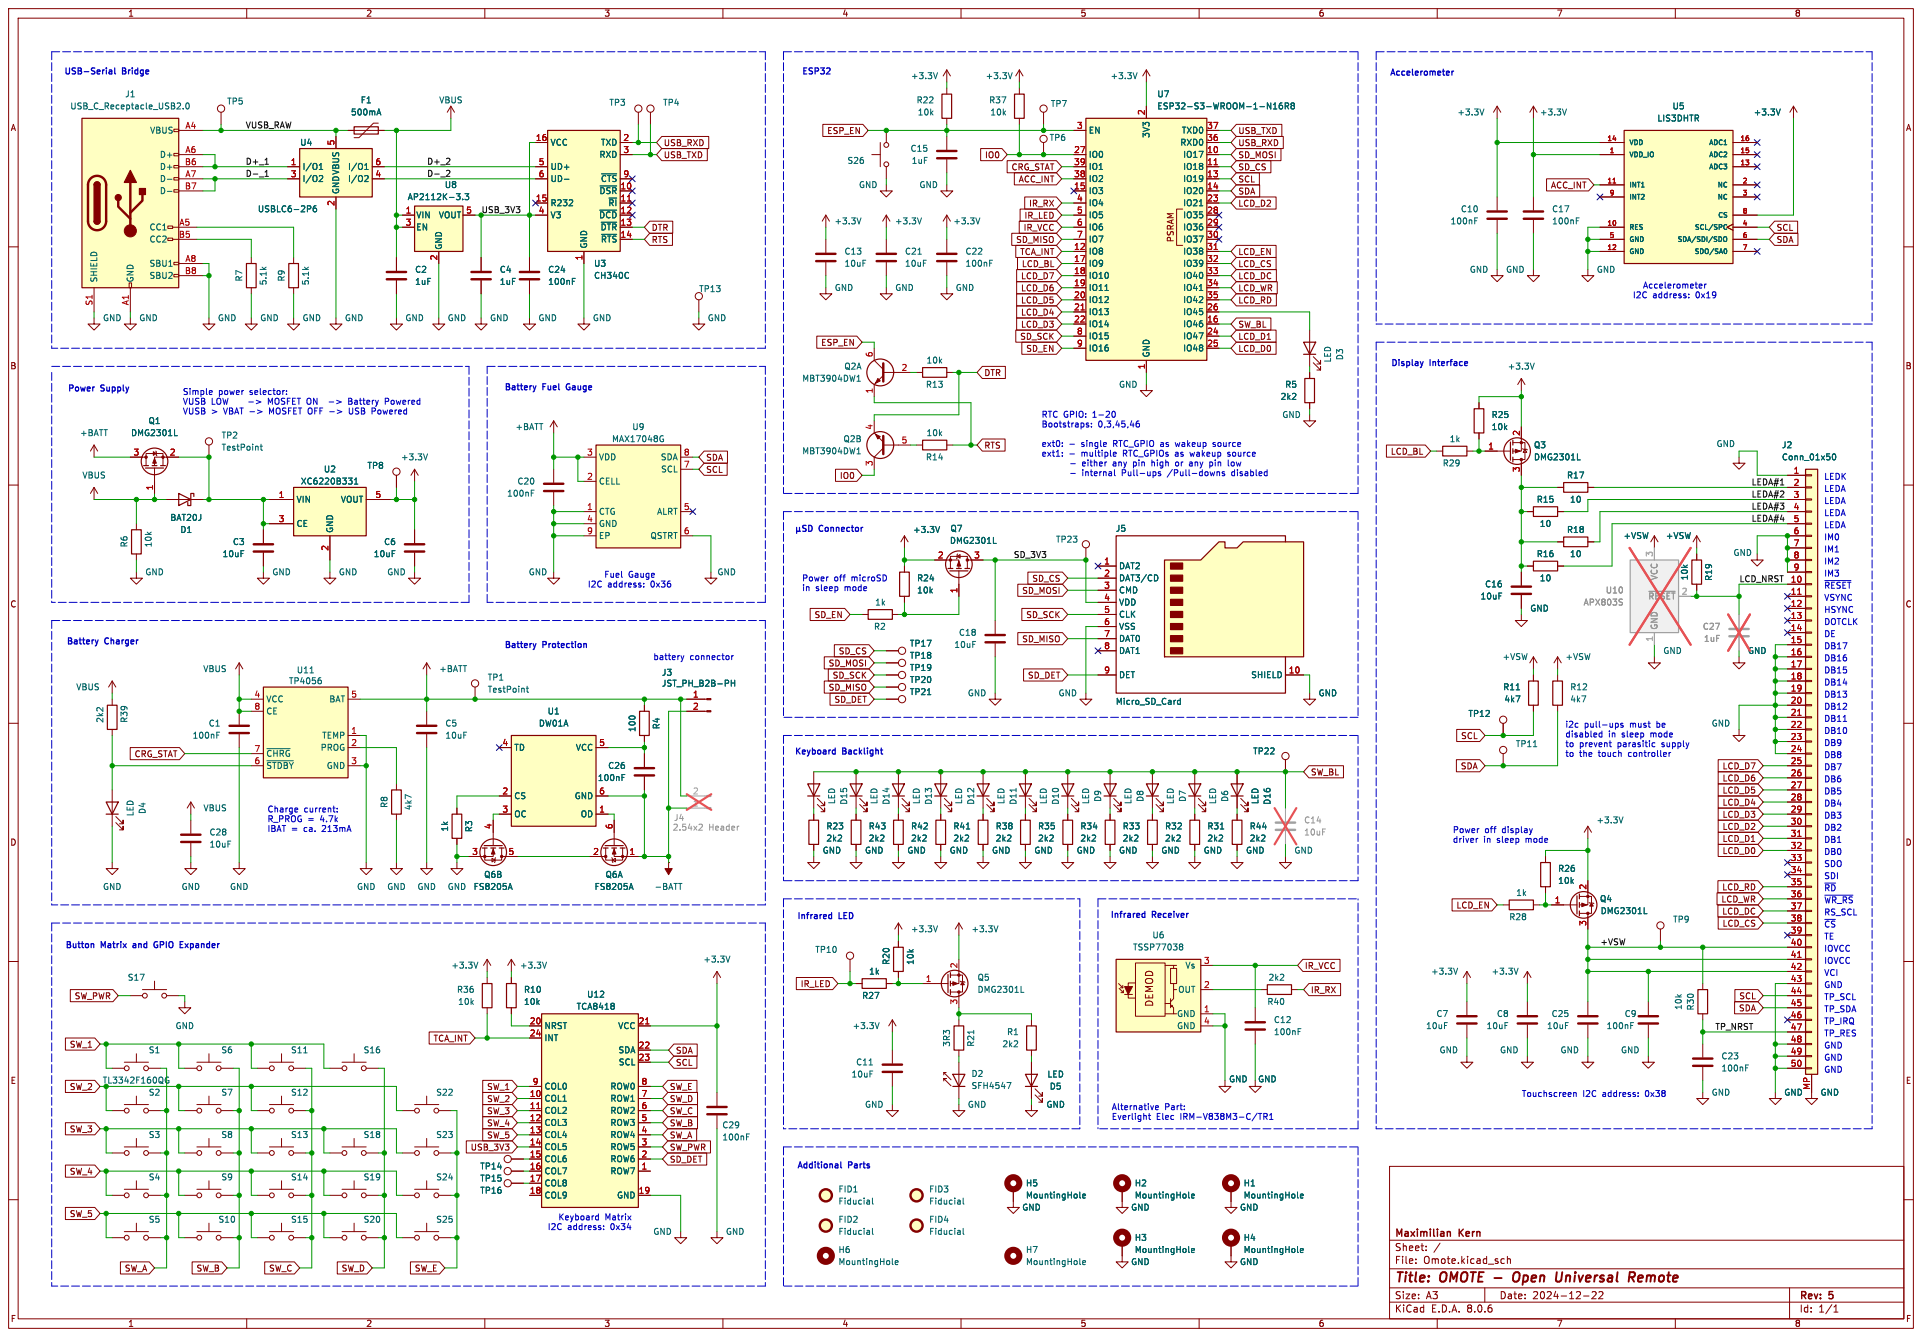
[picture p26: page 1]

1 ~{DSR} 10 ~{RI} 11 ~{DCD} 12 ~{DTR} 13 ~{RTS} 14 R232 15 VCC 16 TXD 2 RXD 3 V3 4 UD+ 5 UD- 6 ~{CTS}9 TP8 C24

1 ~{DSR} 10 ~{RI} 11 ~{DCD} 12 ~{DTR} 13 ~{RTS} 14 R232 15 VCC 16 TXD 2 RXD 3 V3 4 UD+ 5 UD- 6 ~{CTS}9 U3 CH340C

Battery Fuel Gauge Button Matrix and GPIO Expander

ext0: - single RTC_GPIO as wakeup source

- either any pin high or any pin low

battery connector Fuel Gauge
I2C address: 0x36

Power off display driver in sleep mode Power off microSD

GND 1 OUT 2 Vs 3 GND 4 U6 TSSP77038

Id: 1/1 Title: OMOTE - Open Universal Remote

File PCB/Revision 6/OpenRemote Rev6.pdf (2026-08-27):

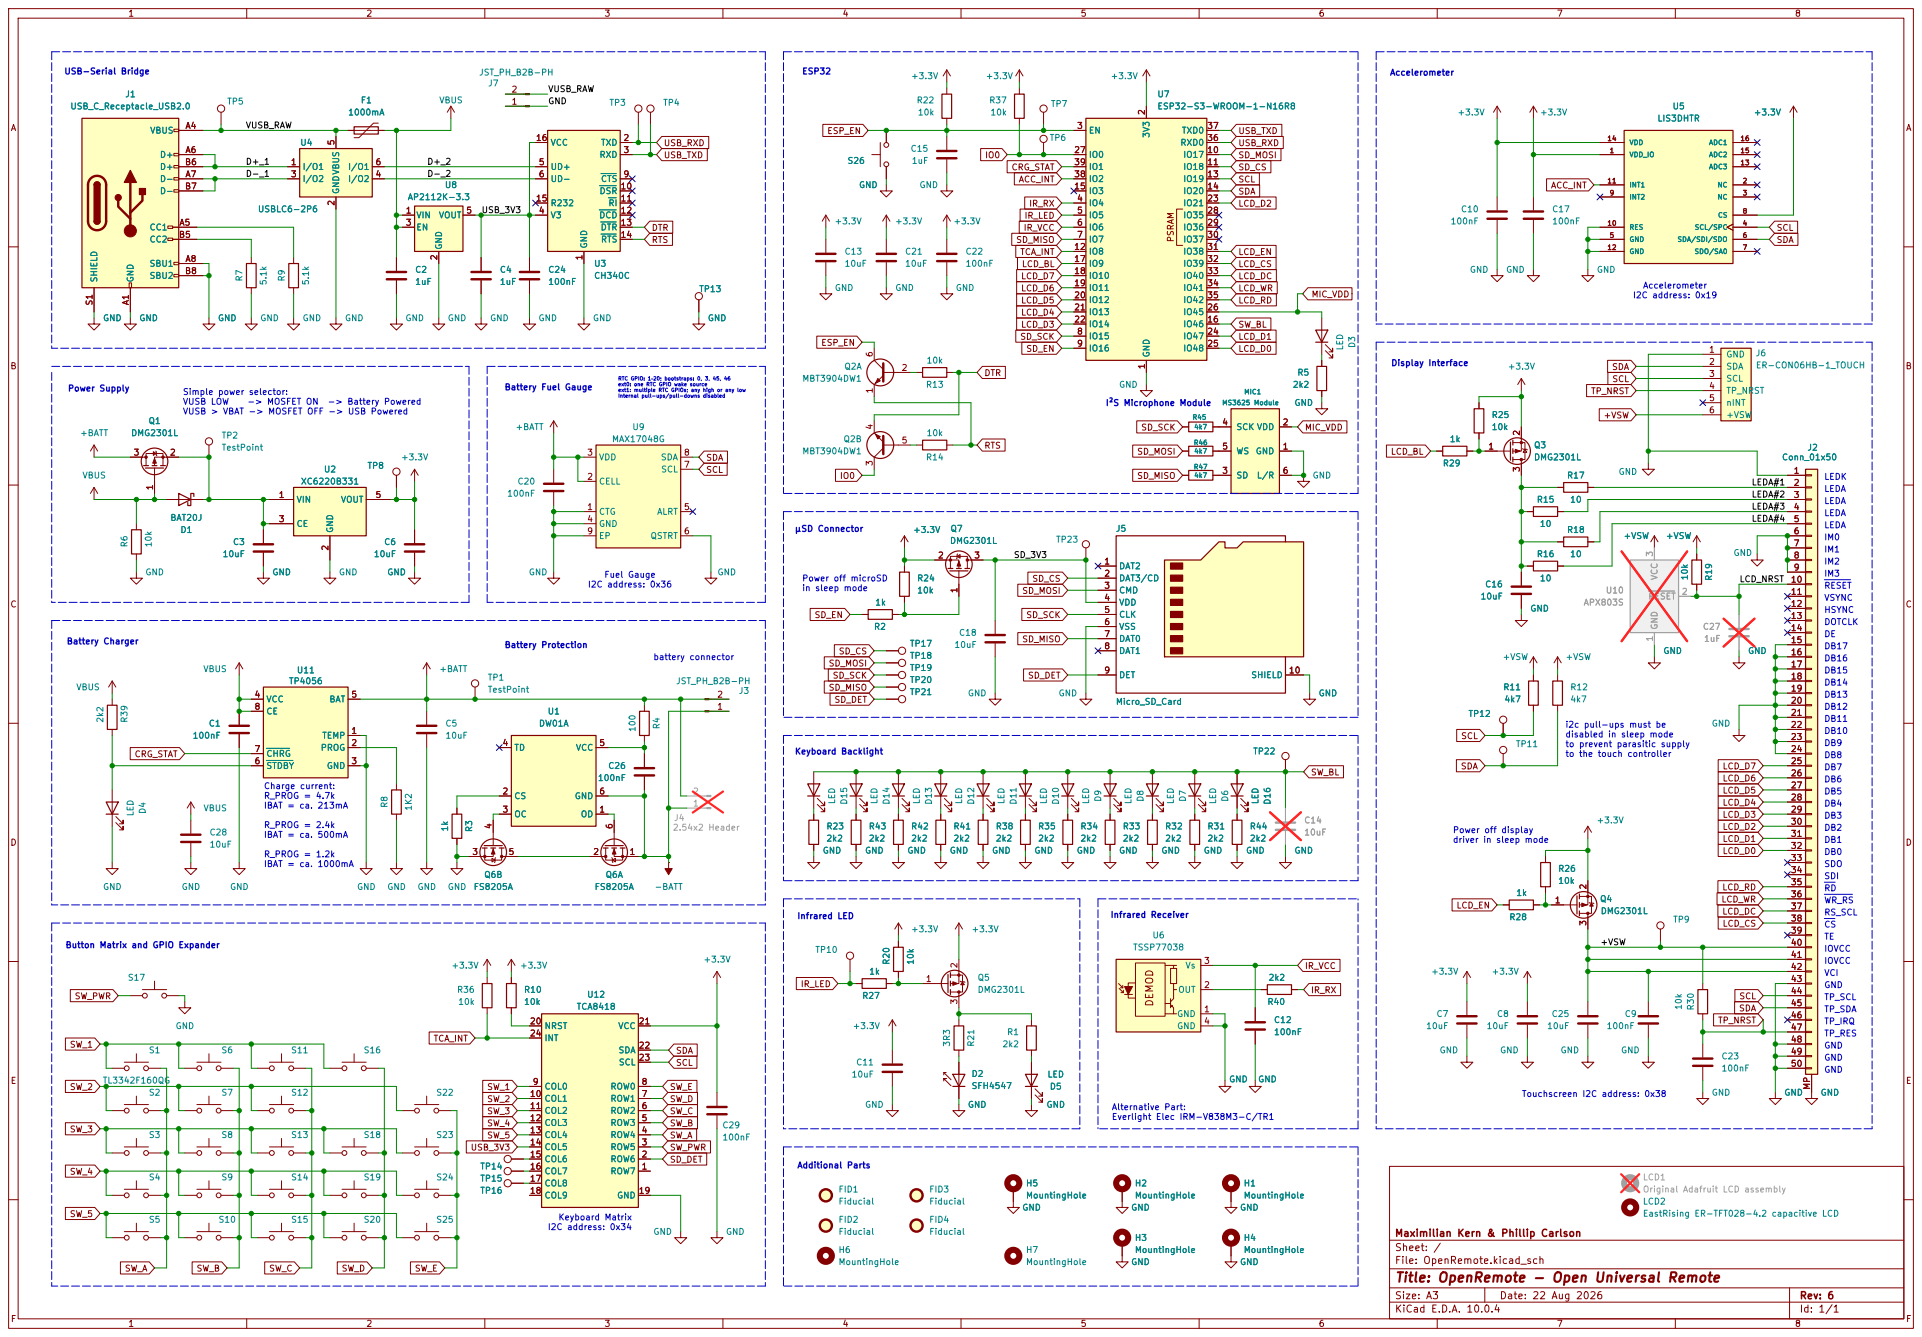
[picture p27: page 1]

VUSB > VBAT -> MOSFET OFF -> USB Powered Power Supply

RTC GPIO: 1–20; bootstraps: 0, 3, 45, 46
ext0: one RTC GPIO wake source

IM2 Power off display driver in sleep mode

battery connector Fuel Gauge

DB11 Button Matrix and GPIO Expander

i2c pull-ups must be disabled in sleep mode

to prevent parasitic supply
to the touch controller

41 41
42 42
43 43

INT 24 | SW_C

Alternative Part: Everlight Elec IRM-V838M3-C/TR1

Additional Parts Keyboard Matrix

LCD1 Original Adafruit LCD assembly LCD2

EastRising ER-TFT028-4.2 capacitive LCD

Maximilian Kern & Phillip Carlson
Sheet: /
File: OpenRemote.kicad_sch
Title: OpenRemote - Open Universal Remote

Size: A3 | Rev: 6 | F Date: 22 Aug 2026
KiCad E.D.A. 10.0.4 | Id: 1/1

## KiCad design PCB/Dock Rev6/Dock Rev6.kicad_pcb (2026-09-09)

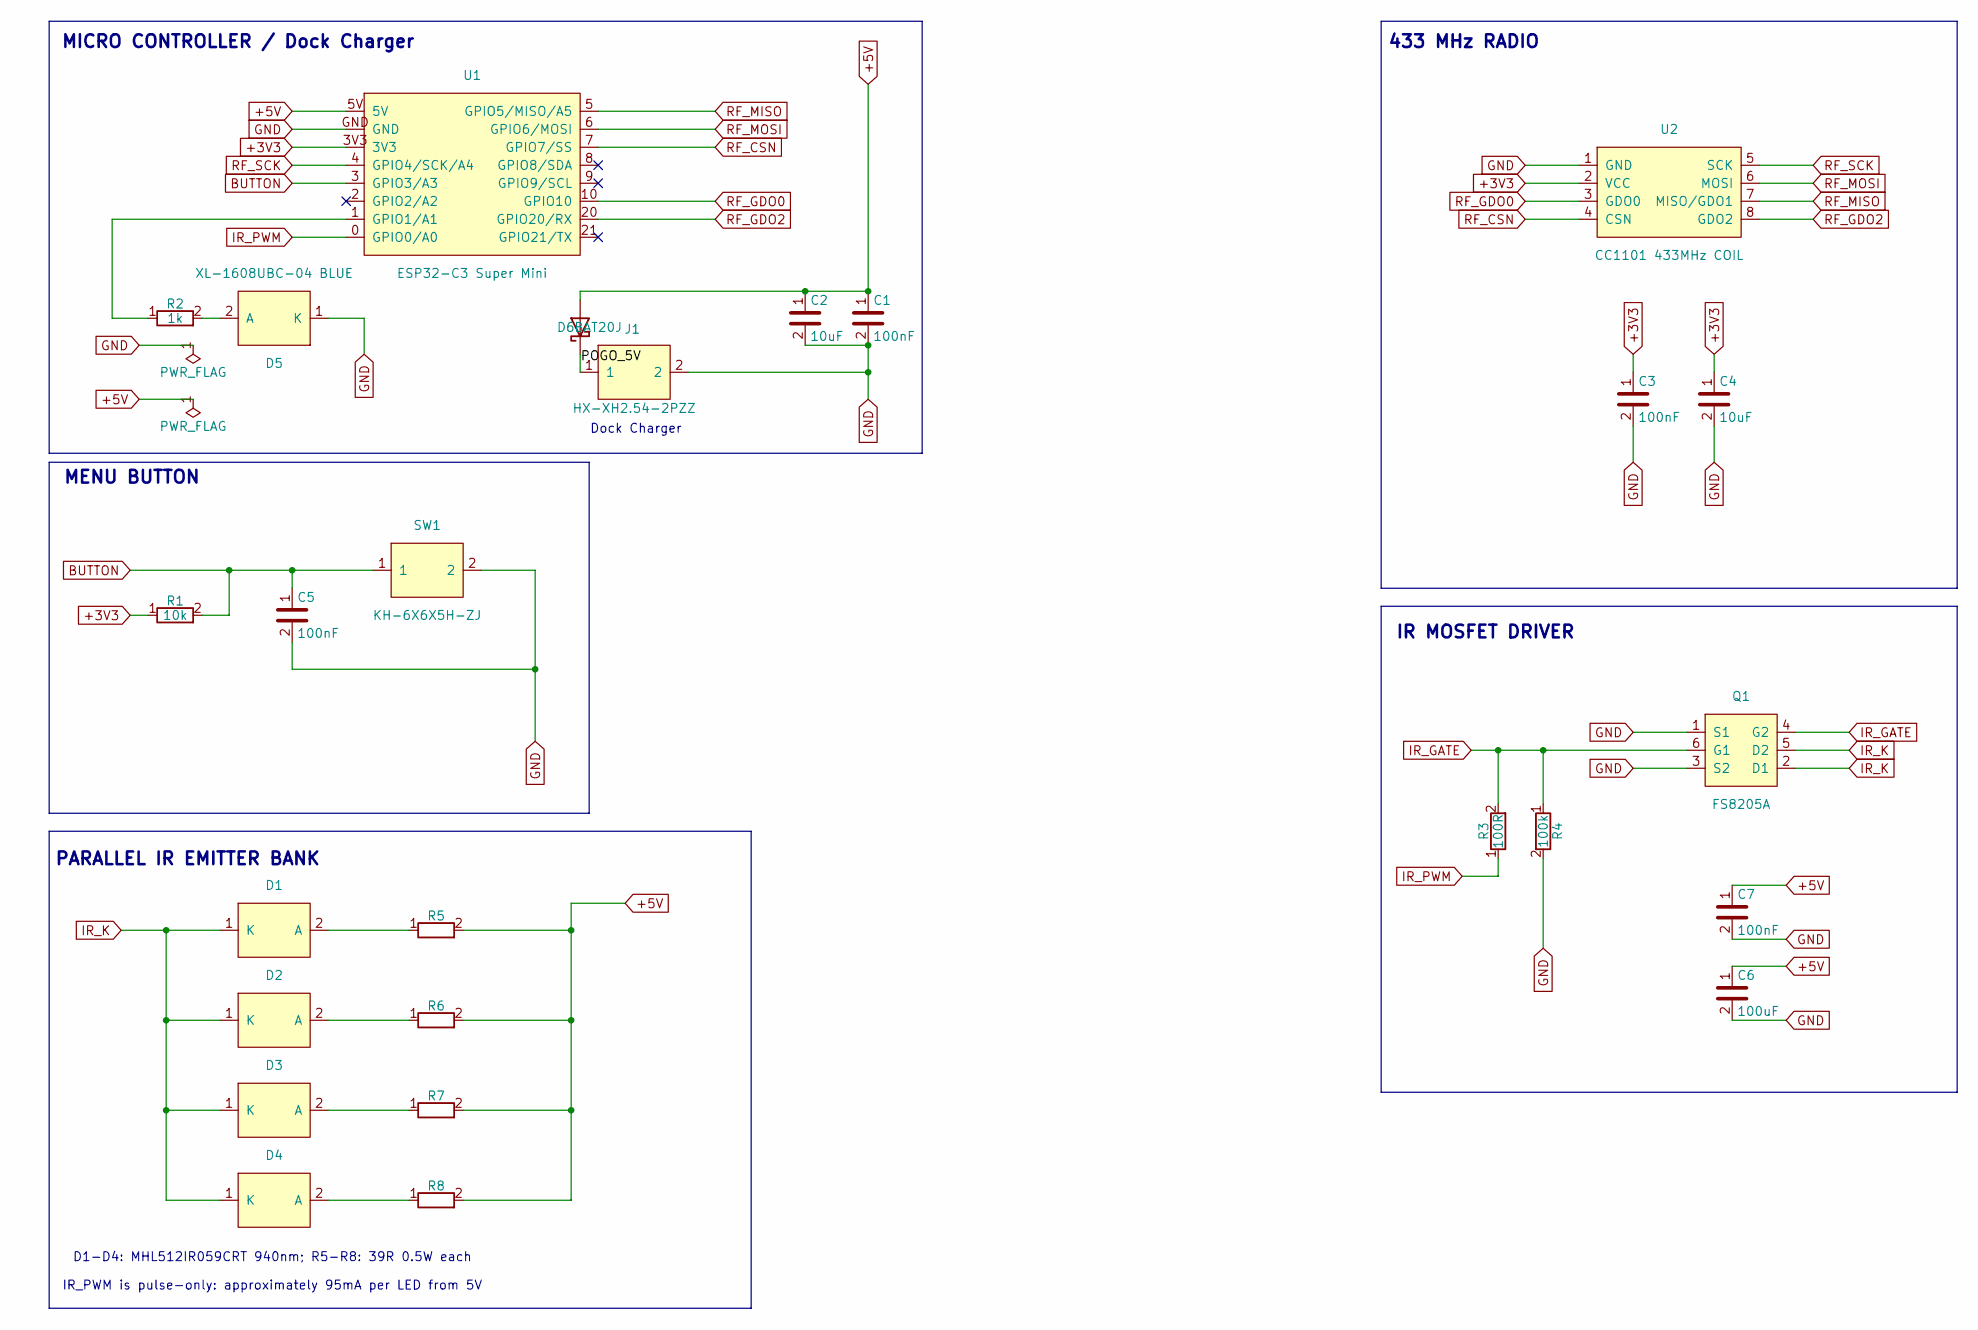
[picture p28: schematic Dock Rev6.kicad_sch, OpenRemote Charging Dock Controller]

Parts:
C1, C3, C5, C7: 100nF; C_0603_1608Metric
C2, C4: 10uF; C_0805_2012Metric
C6: 100uF; CP_Radial_D5.0mm_P2.50mm
D1: MHL512IR059CRT 940nm; IR_LED_THT_D1_with_Assembly3D
D2, D3, D4: MHL512IR059CRT 940nm; LED_5mm_Green_THT
D5: XL-1608UBC-04 BLUE; LED_0603_1608Metric_NoSilk; LCSC C965807
D6: BAT20J; D_SOD-323; LCSC C49238173
J1: HX-XH2.54-2PZZ; HX-XH2.54-2PZZ_C42391660
Q1: FS8205A; FS8205A_SOT-23-6
R1: 10k; R_0603_1608Metric
R2: 1k; R_0603_1608Metric
R3: 100R; R_0603_1608Metric
R4: 100k; R_0603_1608Metric
R5, R6, R7, R8: 39R 0.5W; R_Axial_DIN0411_L9.9mm_D3.6mm_P15.24mm_Horizontal
SW1: KH-6X6X5H-ZJ; SW-TH_KH-6X6X5H-ZJ
U1: ESP32-C3 Super Mini; ESP32-C3_SuperMini_Header_2x08_P2.54mm
U2: CC1101 433MHz COIL; CC1101_433MHz_Coil_Module_2x04_P2.54mm

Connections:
+3V3: C3.1, C4.1, R1.1, U1.3V3, U2.2 (VCC)
BUTTON: C5.1, R1.2, SW1.1, U1.3 (GPIO3/A3)
GND: C1.2, C2.2, C3.2, C4.2, C5.2, C6.2, C7.2, D5.1 (K), J1.2, Q1.1 (S1), Q1.3 (S2), R4.2, SW1.2, U1.GND, U2.1 (GND)
IR_GATE: Q1.4 (G2), Q1.6 (G1), R3.2, R4.1
IR_K: D1.1 (K), D2.1 (K), D3.1 (K), D4.1 (K), Q1.2 (D1), Q1.5 (D2)
IR_PWM: R3.1, U1.0 (GPIO0/A0)
unnamed: D1.2 (A), R5.1
unnamed: D2.2 (A), R6.1
unnamed: D3.2 (A), R7.1
unnamed: D4.2 (A), R8.1
unnamed: D5.2 (A), R2.2
unnamed: R2.1, U1.1 (GPIO1/A1)
RF_CSN: U1.7 (GPIO7/SS), U2.4 (CSN)
RF_GDO0: U1.10 (GPIO10), U2.3 (GDO0)
RF_GDO2: U1.20 (GPIO20/RX), U2.8 (GDO2)
RF_MISO: U1.5 (GPIO5/MISO/A5), U2.7 (MISO/GDO1)
RF_MOSI: U1.6 (GPIO6/MOSI), U2.6 (MOSI)
RF_SCK: U1.4 (GPIO4/SCK/A4), U2.5 (SCK)

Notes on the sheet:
PARALLEL IR EMITTER BANK
D1-D4: MHL512IR059CRT 940nm; R5-R8: 39R 0.5W each
IR MOSFET DRIVER
IR_PWM is pulse-only: approximately 95mA per LED from 5V
MENU BUTTON
433 MHz RADIO
Dock Charger
MICRO CONTROLLER / Dock Charger

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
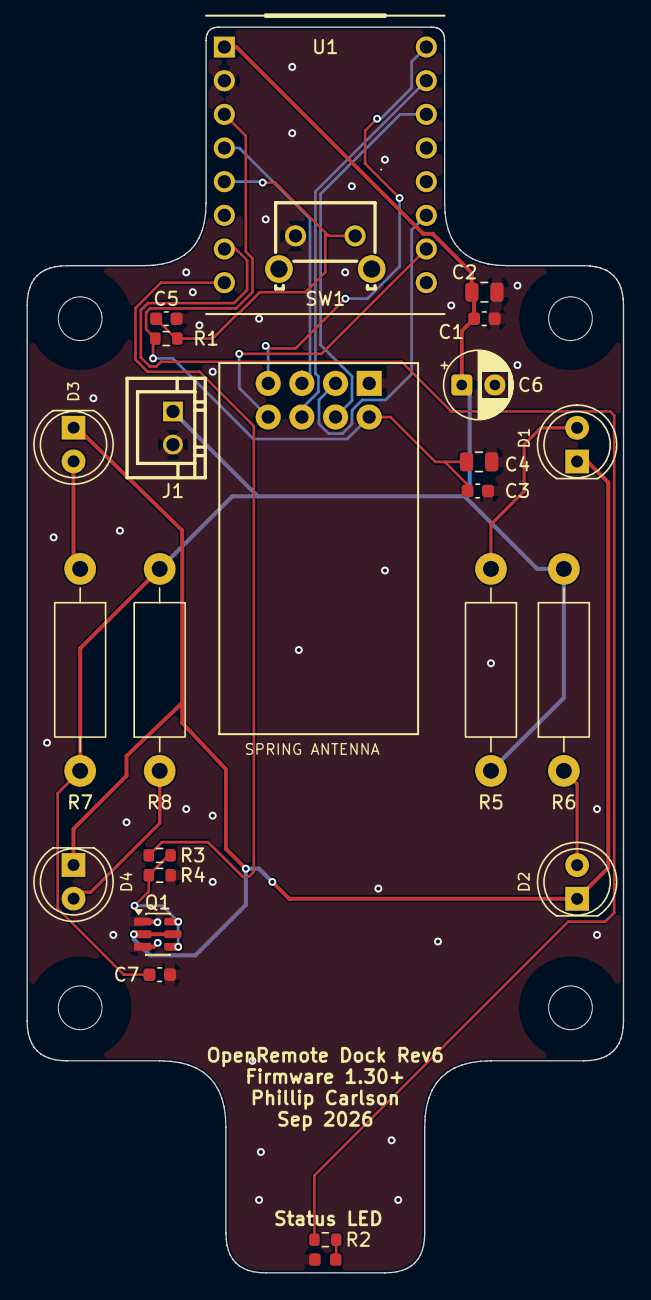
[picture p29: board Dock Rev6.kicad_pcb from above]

Board: 2 copper layers, 45.0 x 94.0 mm, 29 parts (0 on the bottom side), 19 nets.

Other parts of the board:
H1, H2, H3, H4: M3x5 PCB SCREW / 3.3mm NPTH; MountingHole_3.2mm_M3

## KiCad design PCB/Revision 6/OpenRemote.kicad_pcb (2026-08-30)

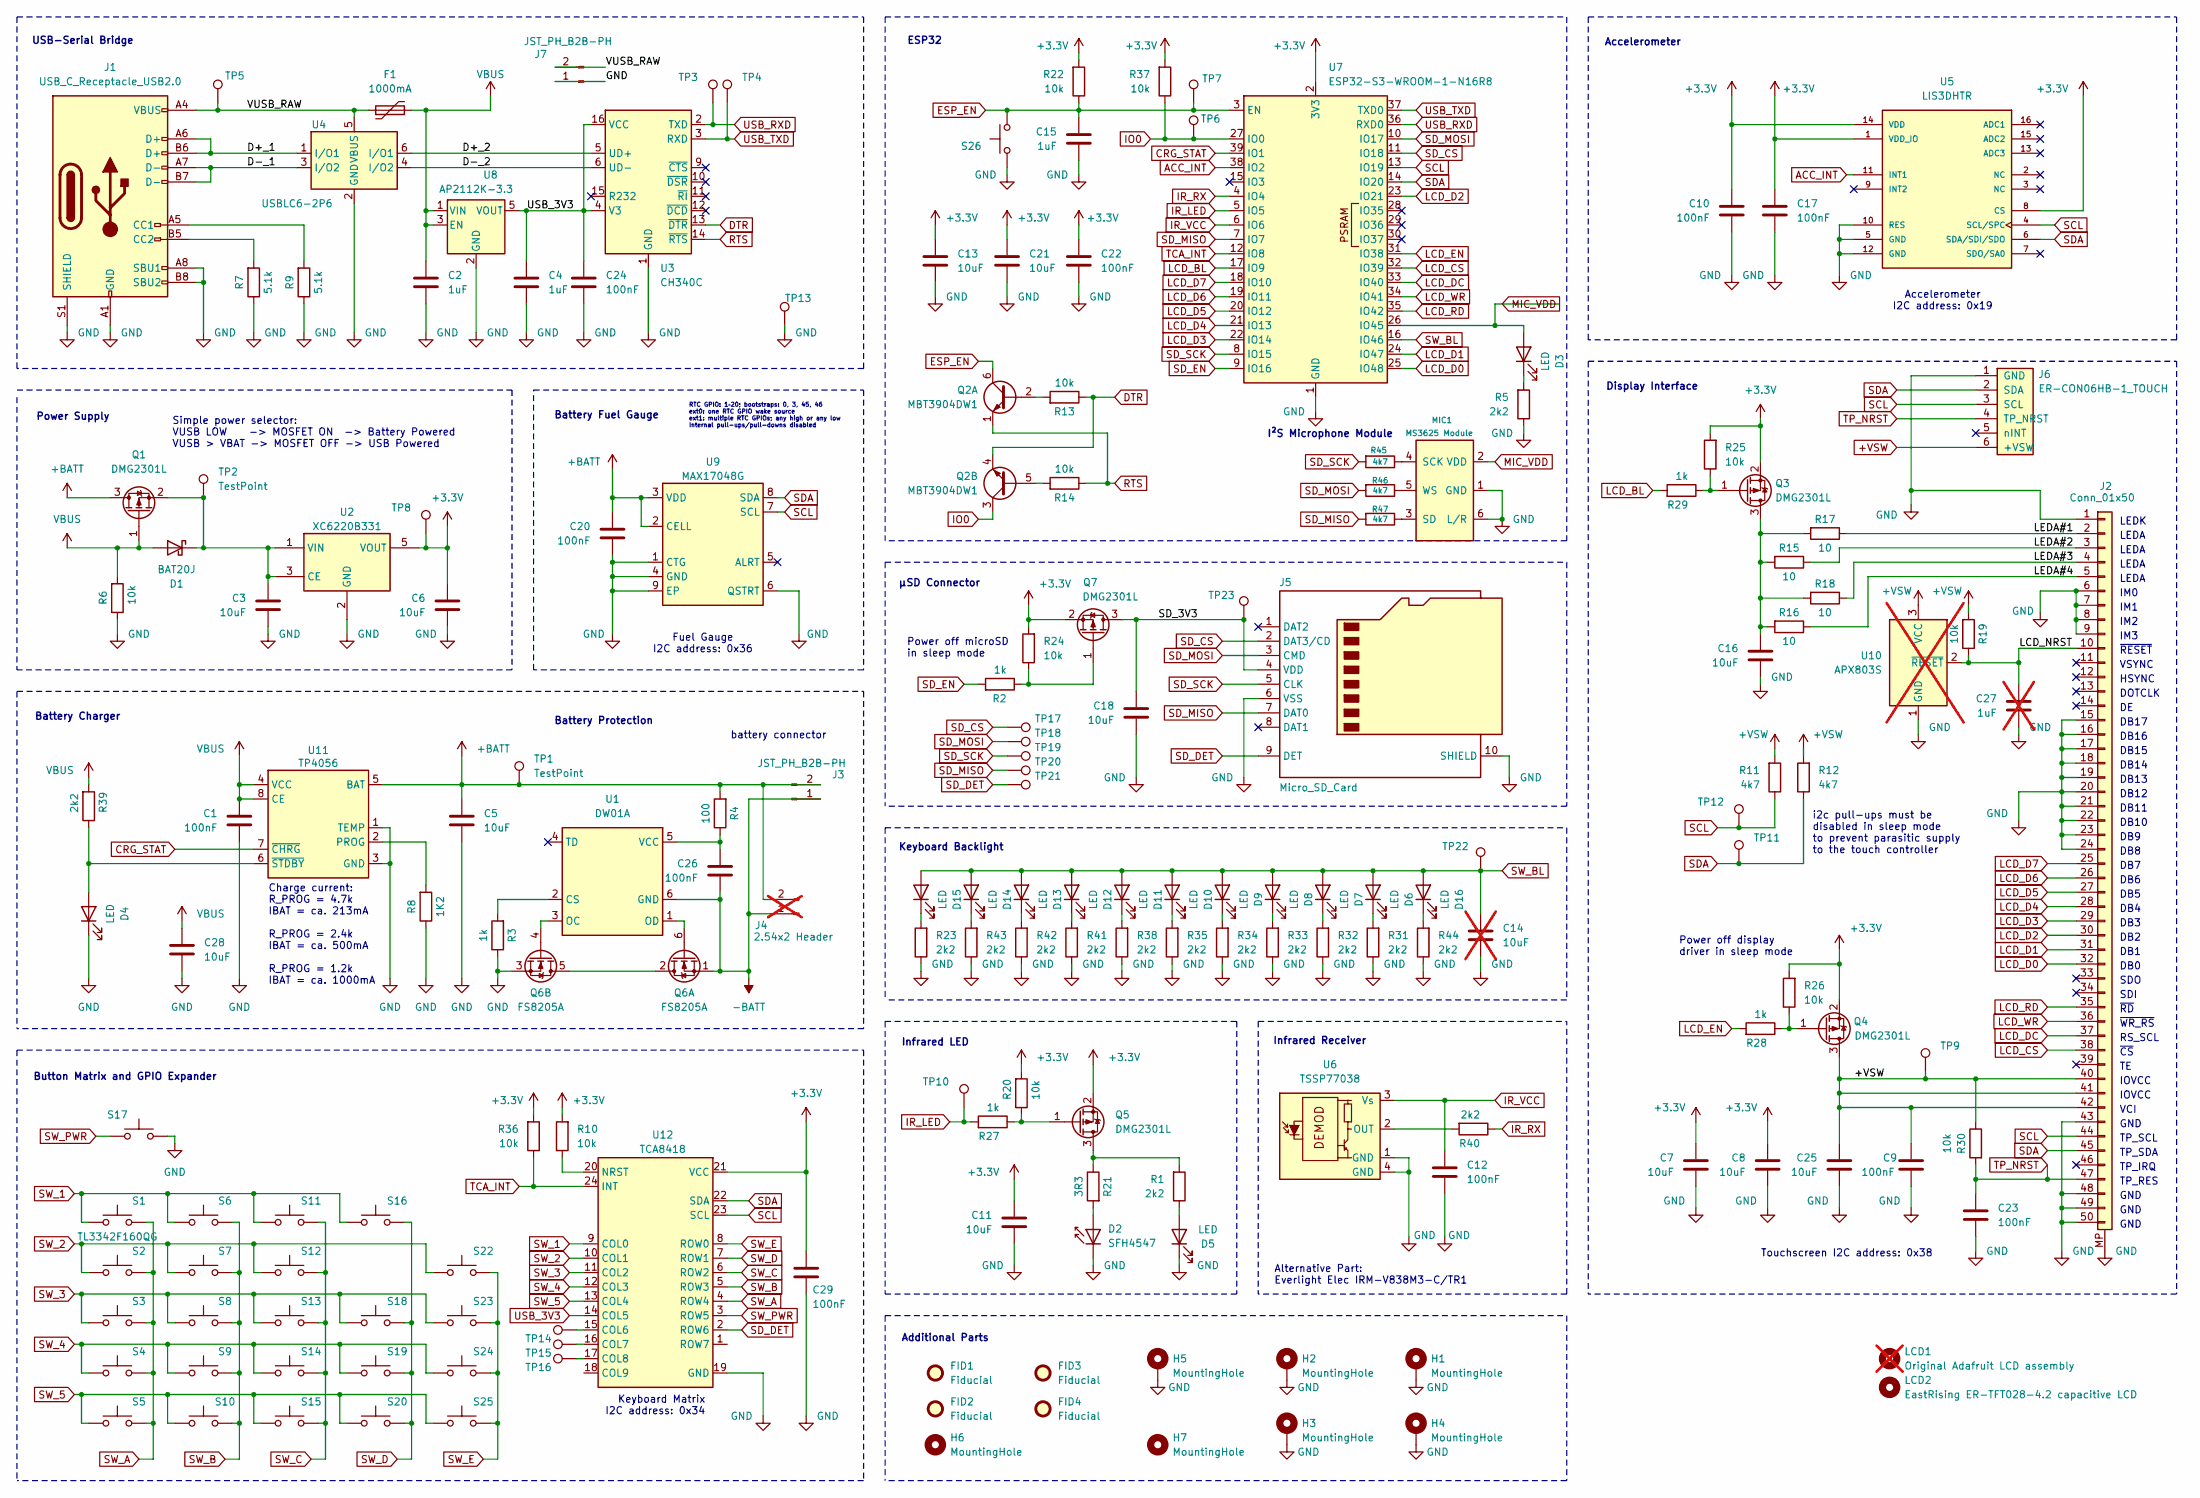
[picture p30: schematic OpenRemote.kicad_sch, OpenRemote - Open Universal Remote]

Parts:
C1, C9, C10, C12, C17, C20, C22, C23, C24, C26, C29: 100nF; C_0603_1608Metric; LCSC C1591
C2, C4, C15: 1uF; C_0603_1608Metric; LCSC C15849
C3, C5, C6, C7, C8, C11, C13, C16, C18, C21, C25, C28: 10uF; C_0805_2012Metric; LCSC C15850
C14: 10uF; C_0805_2012Metric; LCSC C15850; not fitted
C27: 1uF; C_0603_1608Metric; not fitted
D1: BAT20J; D_SOD-323; LCSC C49238173
D2: SFH4547; LED_5mm_Side_Mount; LCSC C405273
D3, D4, D5: LED; LED_0603_1608Metric; LCSC C965807
D6, D7, D8, D9, D10, D11, D12, D13, D14, D15, D16: LED; LED_0603_1608Metric; LCSC C84265
F1: 1000mA; Fuse_1206_3216Metric_Pad1.42x1.75mm_HandSolder; LCSC C220146
FID1, FID2, FID3, FID4: Fiducial; Fiducial_1mm_Mask2mm
H1, H2, H3, H5: MountingHole; MountingHole_3.2mm_M3_Pad_Via
H4: MountingHole; MountingHole_3.2mm_M3
H6, H7: MountingHole; MountingHole_2.5mm
J1: USB_C_Receptacle_USB2.0; USB_C_Receptacle_HRO_TYPE-C-31-M-12; LCSC C2982555
J2: Conn_01x50; TFT_2.83IN_240X320_50PIN; LCSC C11098
J3, J7: JST_PH_B2B-PH; JST_PH_B2B-PH-SM4-TB_1x02-1MP_P2.00mm_Vertical; LCSC C160352
J4: 2.54x2 Header; PinHeader_1x02_P2.54mm_Vertical; not fitted
J5: Micro_SD_Card; MicroSD Slot TF-01A; LCSC C20613191
J6: ER-CON06HB-1_TOUCH; ER-CON06HB-1_Compatible_1x06_P0.50mm_BottomContact; LCSC C202118
LCD1: Original Adafruit LCD assembly; Adafruit_280QV10_MECHANICAL; not fitted
LCD2: EastRising ER-TFT028-4.2 capacitive LCD; ER-TFT028-4.2_MECHANICAL
MIC1: MS3625 Module; MS3625_Module_Back_Mount_SMD
Q1, Q3, Q4, Q5, Q7: DMG2301L; SOT-23; LCSC C102619
Q2: MBT3904DW1; SOT-363_SC-70-6; LCSC C110150
Q6: FS8205A; SOT-23-6; LCSC C908265
R1, R5, R23, R31, R32, R33, R34, R35, R38, R39, R40, R41, R42, R43, R44: 2k2; R_0603_1608Metric; LCSC C114662
R2, R3, R27, R28, R29: 1k; R_0603_1608Metric; LCSC C22548
R4: 100; R_0603_1608Metric; LCSC C125923
R6, R10, R13, R14, R19, R20, R22, R24, R25, R26, R30, R36, R37: 10k; R_0603_1608Metric; LCSC C98220
R7, R9: 5.1k; R_0603_1608Metric; LCSC C105580
R8: 1K2; R_0603_1608Metric; LCSC C22765
R11, R12: 4k7; R_0603_1608Metric; LCSC C99782
R15, R16, R17, R18: 10; R_0603_1608Metric; LCSC C109318
R21: 3R3; R_0805_2012Metric; LCSC C313912
R45, R46, R47: 4k7; R_0603_1608Metric; LCSC C23162
S1, S2, S3, S4, S5, S6, S7, S8, S9, S10, S11, S12, S13, S14, S15, S16, S17, S18, S19, S20, S22, S23, S24, S25, S26: TL3342F160QG; SW_SPST_TL3342; LCSC C778172
TP1, TP2, TP3, TP4, TP5, TP6, TP7, TP8, TP9, TP10, TP11, TP12, TP13, TP14, TP15, TP16, TP17, TP18, TP19, TP20, TP21, TP22, TP23: TestPoint; TestPoint_Pad_D1.5mm
U1: DW01A; SOT-23-6; LCSC C18164398
U2: XC6220B331; SOT-23-5; LCSC C86534
U3: CH340C; SOIC-16_3.9x9.9mm_P1.27mm; LCSC C84681
U4: USBLC6-2P6; SOT-666; LCSC C2827693
U5: LIS3DHTR; XDCR_LIS3DHTR; PARTREV 2; LCSC C15134
U6: TSSP77038; Heimdall vertical; LCSC C3291489
U7: ESP32-S3-WROOM-1-N16R8; ESP32-S3-WROOM-1; LCSC C2913202
U8: AP2112K-3.3; SOT-23-5; LCSC C51118
U9: MAX17048G; TDFN-8-1EP_2x2mm_P0.5mm_EP0.8x1.2mm; LCSC C2682616
U10: APX803S; SOT-23; not fitted
U11: TP4056; Infineon_PG-DSO-8-27_3.9x4.9mm_EP2.65x3mm; LCSC C725790
U12: TCA8418; HVQFN-24-1EP_4x4mm_P0.5mm_EP2.5x2.5mm; LCSC C138713

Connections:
+3.3V: C6.1, C7.2, C8.2, C10.1, C11.2, C13.2, C17.1, C21.2, C22.1, C29.1, Q3.2 (S), Q4.2 (S), Q5.2 (S), Q7.2 (S), R10.2, R20.2, R22.2, R24.2, R25.2, R26.2, R36.2, R37.2, TP8.1 (1_1), U2.5 (VOUT), U5.1 (VDD_IO), U5.8 (CS), U5.14 (VDD), U7.2 (3V3), U12.21 (VCC)
+BATT: C5.2, C20.1, J3.2, J4.2, Q1.3 (D), R4.2, TP1.1 (1_1), U9.2 (CELL), U9.3 (VDD), U11.5 (BAT)
+VSW: C9.1, C25.2, J2.40, J2.41, J2.42 (Pin_41), J6.6 (+VSW), Q4.3 (D), R11.2, R12.2, R19.2, R30.1, TP9.1 (1_1), U10.3 (VCC)
-BATT: C26.2, J3.1, J4.1, Q6.1 (S), U1.6 (GND)
/D+_1: J1.A6 (D+), J1.B6 (D+), U4.1 (I/O1)
/D+_2: U3.5 (UD+), U4.6 (I/O1)
/D-_1: J1.A7 (D-), J1.B7 (D-), U4.3 (I/O2)
/D-_2: U3.6 (UD-), U4.4 (I/O2)
/LCD_NRST: C27.2, J2.10, R19.1, U10.2 (~RESET)
/LEDA#1: J2.2, R17.1
/LEDA#2: J2.3, R15.1
/LEDA#3: J2.4, R18.1
/LEDA#4: J2.5, R16.1
/SD_3V3: C18.2, J5.4 (VDD), Q7.3 (D), TP23.1 (1_1)
/VUSB_RAW: F1.1, J1.A4 (VBUS), J1.A9 (VBUS), J1.B4 (VBUS), J1.B9 (VBUS), J7.2, TP5.1 (1_1), U4.5 (VBUS)
ACC_INT: U5.11 (INT1), U7.38 (IO2)
CRG_STAT: U7.39 (IO1), U11.7 (~CHRG)
DTR: Q2.4 (E2), R13.1, U3.13 (~DTR)
ESP_EN: C15.2, Q2.6 (C1), R22.1, S26.2, TP7.1 (1_1), U7.3 (EN)
GND: C1.2, C2.2, C3.1, C4.2, C5.1, C6.2, C7.1, C8.1, C9.2, C10.2, C11.1, C12.2, C13.1, C14.1, C15.1, C16.1, C17.2, C18.1, C20.2, C21.1, C22.2, C23.1, C24.2, C25.1, C27.1, C28.1, C29.2, D2.1 (K), D4.1 (K), D5.1 (K), H1.1 (1_1), H2.1 (1_1), H3.1 (1_1), H4.1, H5.1 (1_1), J1.A1 (GND), J1.A8 (SBU1), J1.A12 (GND), J1.B1 (GND), J1.B8 (SBU2), J1.B12 (GND), J1.S1 (SHIELD), J2.1, J2.6, J2.7, J2.8, J2.9, J2.15, J2.16, J2.17, J2.18, J2.19, J2.20, J2.21, J2.22, J2.23, J2.24, J2.43, J2.48, J2.49, J2.50, J2.MP, J5.6 (VSS), J5.10 (SHIELD), J6.1 (GND), J7.1, MIC1.1 (GND), MIC1.6 (L/R), Q6.3 (S), R3.1, R5.1, R6.1, R7.1, R8.1, R9.1, R23.1, R31.1, R32.1, R33.1, R34.1, R35.1, R38.1, R41.1, R42.1, R43.1, R44.1, S17.1, S26.1, TP13.1 (1_1), U2.2 (GND), U3.1 (GND), U4.2 (GND), U5.5 (GND), U5.10 (RES), U5.12 (GND), U6.1 (GND), U6.4 (GND), U7.1 (GND), U7.40 (GND), U7.41 (GND), U8.2 (GND), U9.1 (CTG), U9.4 (GND), U9.6 (QSTRT), U9.9 (EP), U10.1 (GND), U11.1 (TEMP), U11.3 (GND), U11.9 (GND), U12.19 (GND)
IO0: Q2.3 (C2), R37.1, TP6.1 (1_1), U7.27 (IO0)
IR_LED: R27.2, TP10.1 (1_1), U7.5 (IO5)
IR_RX: R40.1, U7.4 (IO4)
IR_VCC: C12.1, U6.3 (Vs), U7.6 (IO6)
LCD_BL: R29.2, U7.17 (IO9)
LCD_CS: J2.38, U7.32 (IO39)
LCD_D0: J2.32, U7.25 (IO48)
LCD_D1: J2.31, U7.24 (IO47)
LCD_D2: J2.30, U7.23 (IO21)
LCD_D3: J2.29, U7.22 (IO14)
LCD_D4: J2.28, U7.21 (IO13)
LCD_D5: J2.27, U7.20 (IO12)
LCD_D6: J2.26, U7.19 (IO11)
LCD_D7: J2.25, U7.18 (IO10)
LCD_DC: J2.37, U7.33 (IO40)
LCD_EN: R28.2, U7.31 (IO38)
LCD_RD: J2.35, U7.35 (IO42)
LCD_WR: J2.36, U7.34 (IO41)
MIC_VDD: D3.2 (A), MIC1.2 (VDD), U7.26 (IO45)
unnamed: C3.2, D1.1 (K), Q1.2 (S), TP2.1 (1_1), U2.1 (VIN), U2.3 (CE)
unnamed: D2.2 (A), R21.2
unnamed: D3.1 (K), R5.2
unnamed: D4.2 (A), R39.1, U11.6 (~STDBY)
unnamed: D5.2 (A), R1.1
unnamed: D6.1 (K), R31.2
unnamed: D7.1 (K), R32.2
unnamed: D8.1 (K), R33.2
unnamed: D9.1 (K), R34.2
unnamed: D10.1 (K), R35.2
unnamed: D11.1 (K), R38.2
unnamed: D12.1 (K), R41.2
unnamed: D13.1 (K), R42.2
unnamed: D14.1 (K), R43.2
unnamed: D15.1 (K), R23.2
unnamed: D16.1 (K), R44.2
unnamed: J1.A5 (CC1), R9.2
unnamed: J1.B5 (CC2), R7.2
unnamed: MIC1.4 (SCK), R45.1
unnamed: MIC1.3 (SD), R47.1
unnamed: MIC1.5 (WS), R46.1
unnamed: Q2.2 (B1), R13.2
unnamed: Q2.5 (B2), R14.2
unnamed: C16.2, Q3.3 (D), R15.2, R16.2, R17.2, R18.2
unnamed: Q3.1 (G), R25.1, R29.1
unnamed: Q4.1 (G), R26.1, R28.1
unnamed: Q5.3 (D), R1.2, R21.1
unnamed: Q5.1 (G), R20.1, R27.1
unnamed: Q6.2 (D), Q6.5 (D)
unnamed: Q6.6 (G), U1.1 (OD)
unnamed: Q6.4 (G), U1.3 (OC)
unnamed: Q7.1 (G), R2.1, R24.1
unnamed: R3.2, U1.2 (CS)
unnamed: C26.1, R4.1, U1.5 (VCC)
unnamed: R40.2, U6.2 (OUT)
unnamed: R8.2, U11.2 (PROG)
unnamed: TP14.1 (1_1), U12.15 (COL6)
unnamed: TP15.1 (1_1), U12.16 (COL7)
unnamed: TP16.1 (1_1), U12.17 (COL8)
unnamed: R10.1, U12.20 (NRST)
RTS: Q2.1 (E1), R14.1, U3.14 (~RTS)
SCL: J2.44, J6.3 (SCL), R11.1, TP12.1 (1_1), U5.4 (SCL/SPC), U7.13 (IO19), U9.7 (SCL), U12.23 (SCL)
SDA: J2.45, J6.2 (SDA), R12.1, TP11.1 (1_1), U5.6 (SDA/SDI/SDO), U7.14 (IO20), U9.8 (SDA), U12.22 (SDA)
SD_CS: J5.2 (DAT3/CD), TP17.1 (1_1), U7.11 (IO18)
SD_DET: J5.9 (DET), TP21.1 (1_1), U12.2 (ROW6)
SD_EN: R2.2, U7.9 (IO16)
SD_MISO: J5.7 (DAT0), R47.2, TP20.1 (1_1), U7.7 (IO7)
SD_MOSI: J5.3 (CMD), R46.2, TP18.1 (1_1), U7.10 (IO17)
SD_SCK: J5.5 (CLK), R45.2, TP19.1 (1_1), U7.8 (IO15)
SW_1: S1.1, S6.1, S11.1, S16.1, U12.9 (COL0)
SW_2: S2.1, S7.1, S12.1, S22.1, U12.10 (COL1)
SW_3: S3.1, S8.1, S13.1, S18.1, S23.1, U12.11 (COL2)
SW_4: S4.1, S9.1, S14.1, S19.1, S24.1, U12.12 (COL3)
SW_5: S5.1, S10.1, S15.1, S20.1, S25.1, U12.13 (COL4)
SW_A: S1.2, S2.2, S3.2, S4.2, S5.2, U12.4 (ROW4)
SW_B: S6.2, S7.2, S8.2, S9.2, S10.2, U12.5 (ROW3)
SW_BL: C14.2, D6.2 (A), D7.2 (A), D8.2 (A), D9.2 (A), D10.2 (A), D11.2 (A), D12.2 (A), D13.2 (A), D14.2 (A), D15.2 (A), D16.2 (A), TP22.1 (1_1), U7.16 (IO46)
SW_C: S11.2, S12.2, S13.2, S14.2, S15.2, U12.6 (ROW2)
SW_D: S16.2, S18.2, S19.2, S20.2, U12.7 (ROW1)
SW_E: S22.2, S23.2, S24.2, S25.2, U12.8 (ROW0)
SW_PWR: S17.2, U12.3 (ROW5)
TCA_INT: R36.1, U7.12 (IO8), U12.24 (INT)
TP_NRST: C23.2, J2.47, J6.4 (TP_NRST), R30.2
USB_3V3: C4.1, C24.1, U3.4 (V3), U3.16 (VCC), U8.5 (VOUT), U12.14 (COL5)
USB_RXD: TP3.1 (1_1), U3.2 (TXD), U7.36 (RXD0)
USB_TXD: TP4.1 (1_1), U3.3 (RXD), U7.37 (TXD0)
VBUS: C1.1, C2.1, C28.2, D1.2 (A), F1.2, Q1.1 (G), R6.2, R39.2, U8.1 (VIN), U8.3 (EN), U11.4 (VCC), U11.8 (CE)

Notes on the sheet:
DB6
Accelerometer I2C address: 0x19
DB11
DB14
IM2
DB10
Infrared Receiver
Display Interface
LEDA
DB0
GND
DB16
Alternative Part: Everlight Elec IRM-V838M3-C/TR1
TP_RES
TP_IRQ
LEDK
IM1
IOVCC
Battery Fuel Gauge
~{RESET}
ESP32
RTC GPIO: 1–20; bootstraps: 0, 3, 45, 46 ext0: one RTC GPIO wake source ext1: multiple RTC GPIOs; any high or any low Internal pull-ups/pull-downs disabled
Battery Protection
IM3
DB5
Additional Parts
USB-Serial Bridge
Charge current: R_PROG = 4.7k IBAT = ca. 213mA R_PROG = 2.4k IBAT = ca. 500mA R_PROG = 1.2k IBAT = ca. 1000mA
DB17
TP_SDA
DB7
DB12
DB1
DOTCLK
~{WR_RS}
Infrared LED
µSD Connector
SDI
DB13
DB4

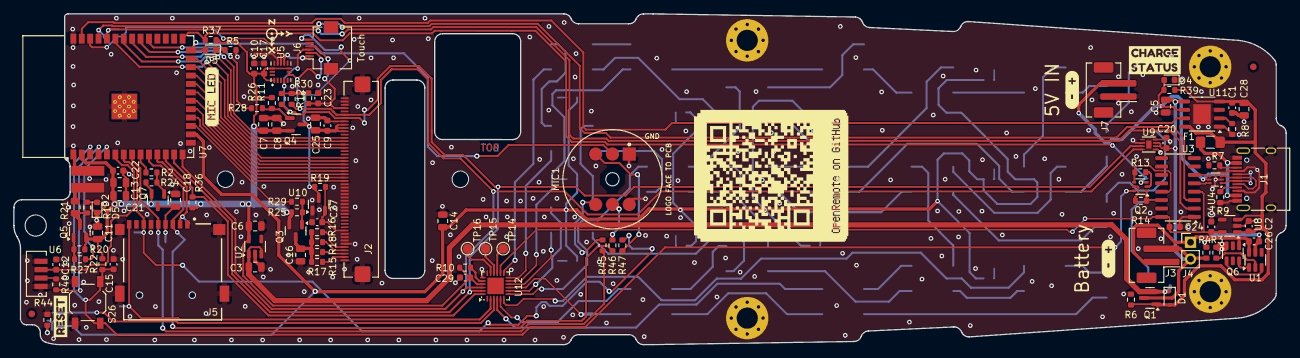
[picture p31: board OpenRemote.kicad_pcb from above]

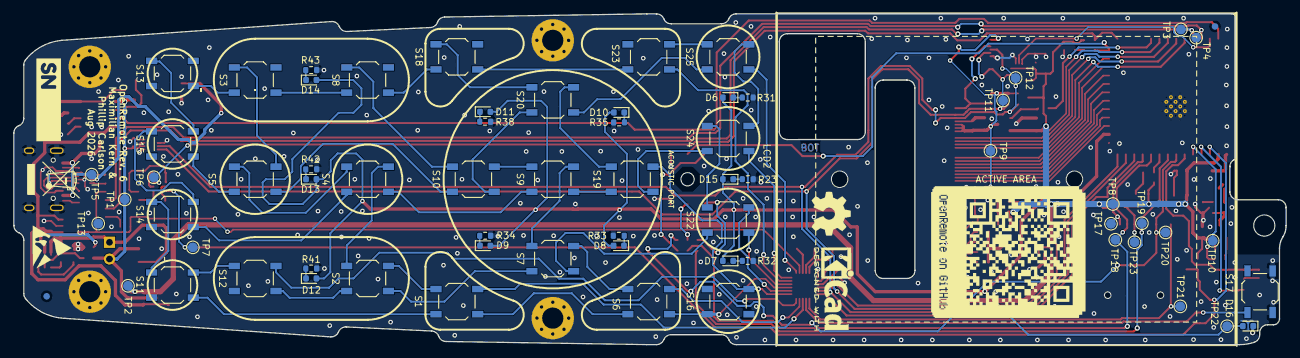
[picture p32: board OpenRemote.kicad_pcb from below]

Board: 2 copper layers, 192.4 x 50.0 mm, 191 parts (70 on the bottom side), 106 nets.

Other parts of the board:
MIC_LED_LABEL: MIC LED; MIC_LED_LABEL
OPENREMOTE_QR: https://github.com/LORDSn1per/OpenRemote-Firmware; OPENREMOTE_GITHUB_QR
OPENREMOTE_QR#2: https://github.com/LORDSn1per/OpenRemote-Firmware; OPENREMOTE_GITHUB_QR
kibuzzard-63D97EAF, kibuzzard-63D97EAF#2: G***; kibuzzard-63D97EAF
kibuzzard-64A91BF0: G***; kibuzzard-64A91BF0
kibuzzard-64A91C1C: G***; kibuzzard-64A91C1C
kibuzzard-64A91C24: G***; kibuzzard-64A91C24
kibuzzard-643EE5B9: G***; kibuzzard-643EE5B9
kibuzzard-643EE600: G***; kibuzzard-643EE600
kibuzzard-644014FA: G***; kibuzzard-644014FA

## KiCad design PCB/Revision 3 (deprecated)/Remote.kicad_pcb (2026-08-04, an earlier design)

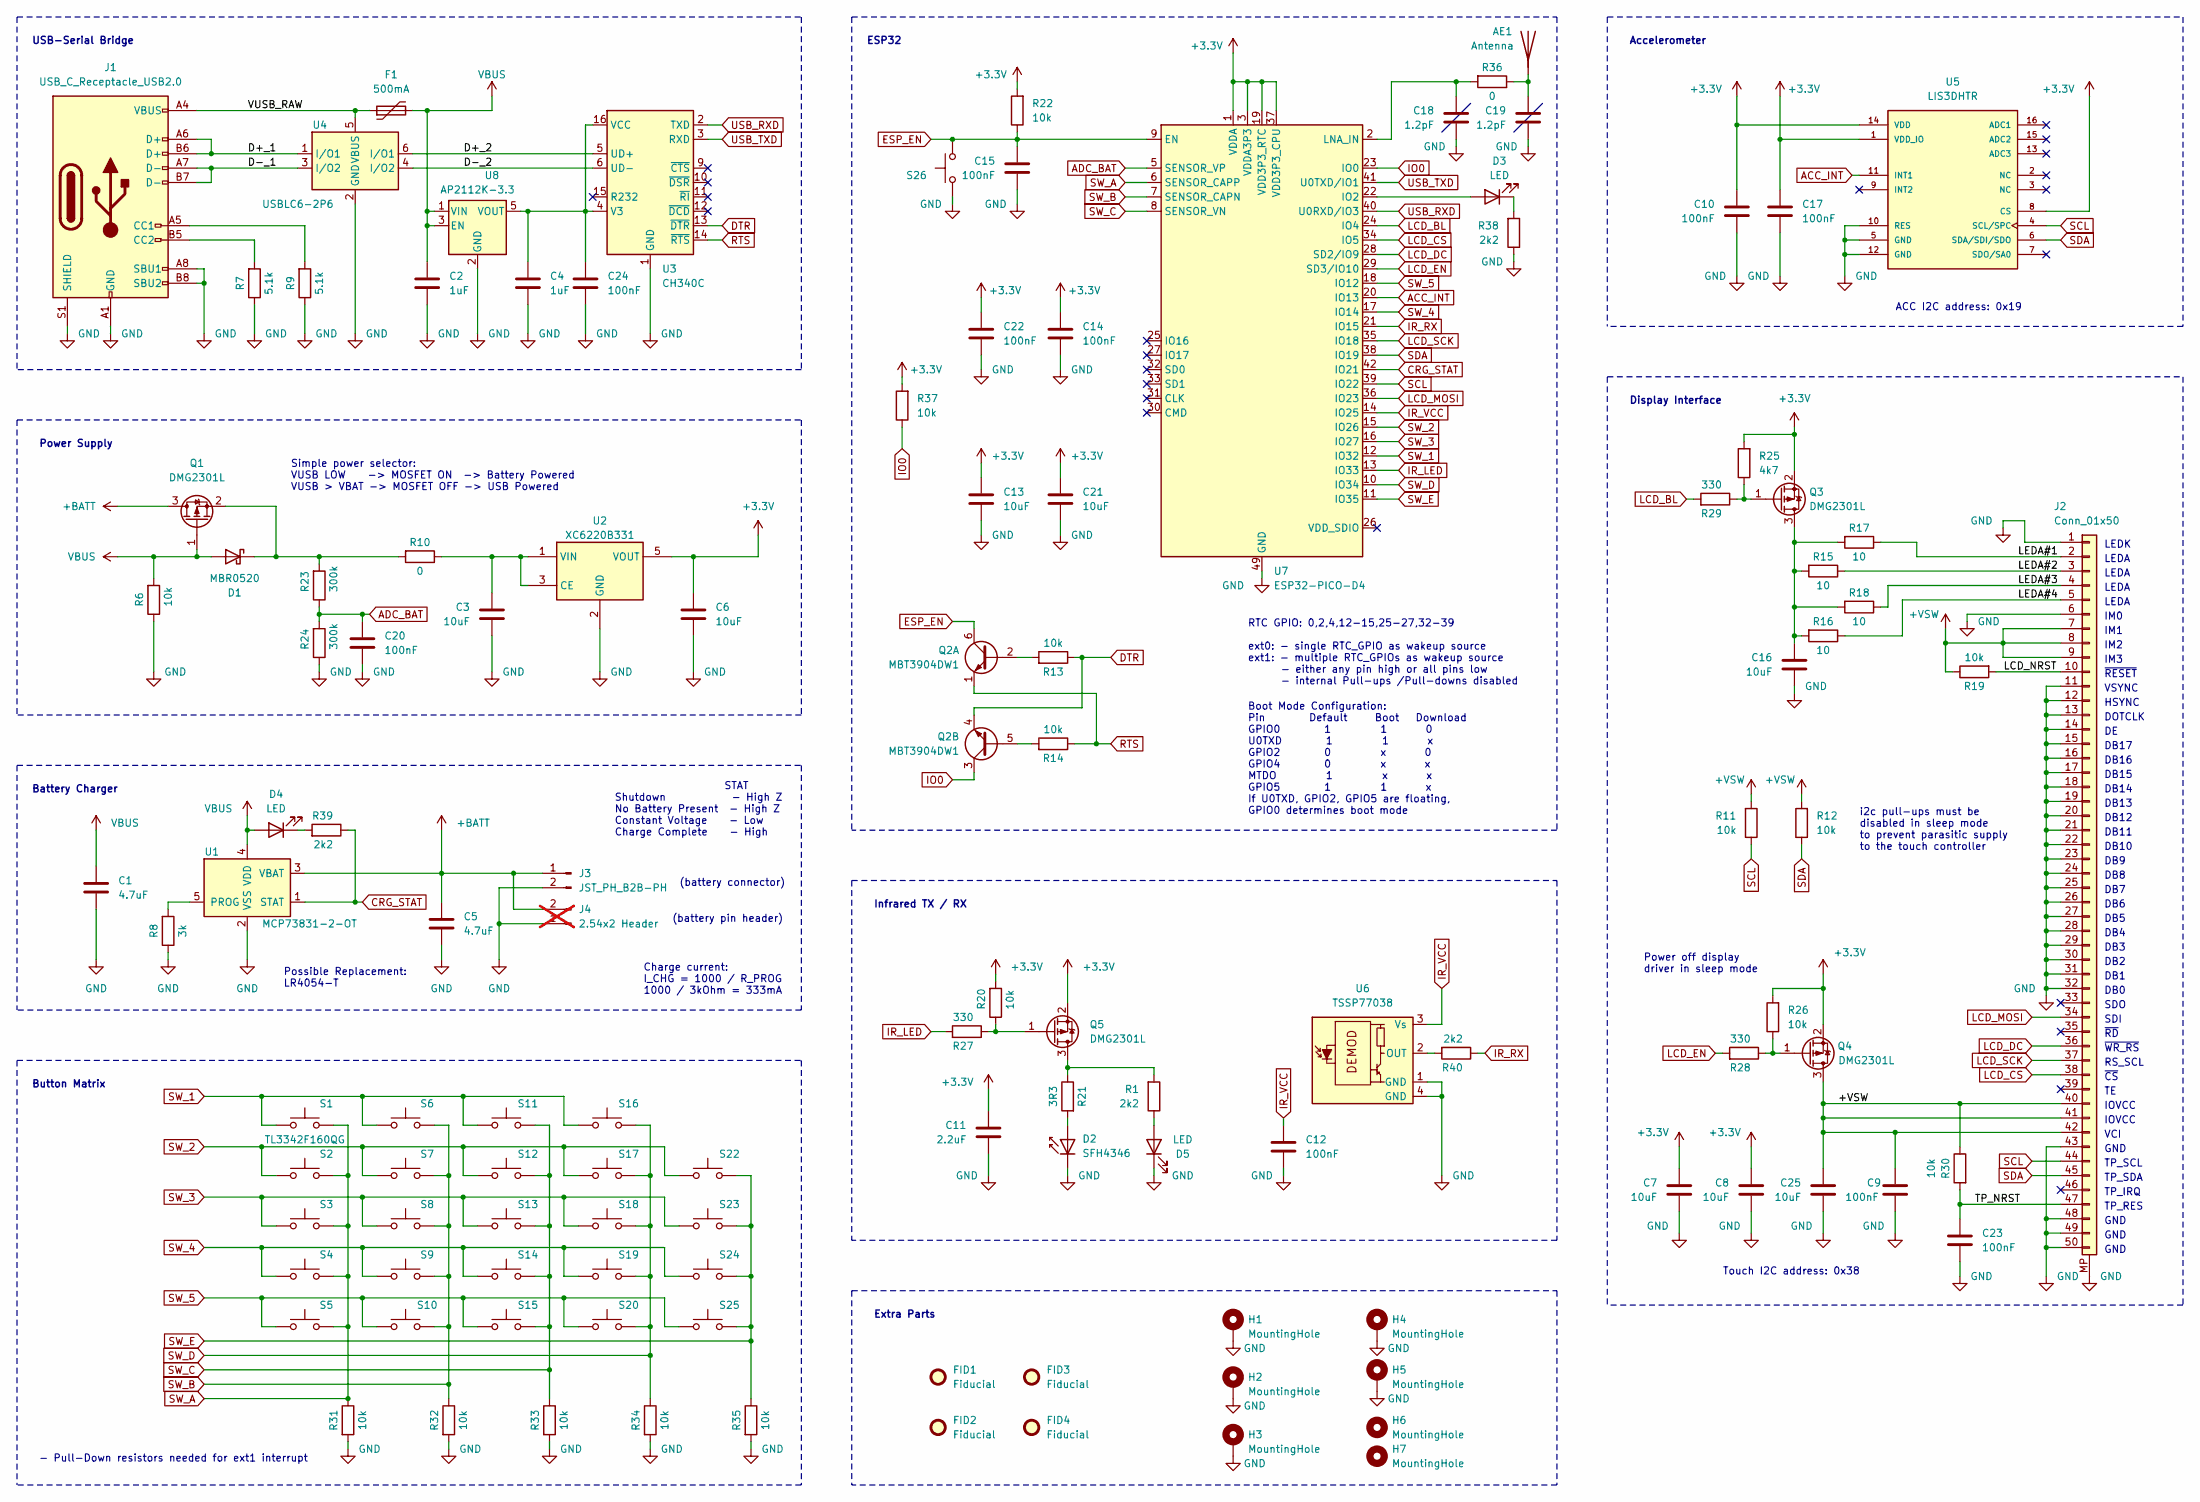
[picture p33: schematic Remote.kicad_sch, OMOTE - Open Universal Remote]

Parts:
AE1: Antenna; RFANT5220110A2T
C1, C5: 4.7uF; C_0603_1608Metric
C2, C4: 1uF; C_0603_1608Metric
C3, C6, C7, C8, C13, C16, C21, C25: 10uF; C_0805_2012Metric
C9, C10, C12, C14, C15, C17, C20, C22, C23, C24: 100nF; C_0603_1608Metric
C11: 2.2uF; C_0603_1608Metric
C18, C19: 1.2pF; C_0603_1608Metric
D1: MBR0520; D_SOD-123
D2: SFH4346; LED_5mm_Side_Mount
D3, D4, D5: LED; LED_0603_1608Metric
F1: 500mA; Fuse_1206_3216Metric_Pad1.42x1.75mm_HandSolder
FID1, FID2, FID3, FID4: Fiducial; Fiducial_1mm_Mask2mm
H1, H2, H3, H4, H5: MountingHole; MountingHole_3.2mm_M3_Pad_Via
H6, H7: MountingHole; MountingHole_2.5mm
J1: USB_C_Receptacle_USB2.0; USB_C_Receptacle_HRO_TYPE-C-31-M-12
J2: Conn_01x50; TFT_2.83IN_240X320_50PIN
J3: JST_PH_B2B-PH; JST_PH_B2B-PH-SM4-TB_1x02-1MP_P2.00mm_Vertical
J4: 2.54x2 Header; PinHeader_1x02_P2.54mm_Vertical; not fitted
Q1, Q3, Q4, Q5: DMG2301L; SOT-23
Q2: MBT3904DW1; SOT-363_SC-70-6
R1, R38, R39, R40: 2k2; R_0603_1608Metric
R6, R11, R12, R13, R14, R19, R20, R22, R26, R30, R31, R32, R33, R34, R35, R37: 10k; R_0603_1608Metric
R7, R9: 5.1k; R_0603_1608Metric
R8: 3k; R_0603_1608Metric
R10, R36: 0; R_0603_1608Metric
R15, R16, R17, R18: 10; R_0603_1608Metric
R21: 3R3; R_0805_2012Metric
R23, R24: 300k; R_0603_1608Metric
R25: 4k7; R_0603_1608Metric
R27, R28, R29: 330; R_0603_1608Metric
S1, S2, S3, S4, S5, S6, S7, S8, S9, S10, S11, S12, S13, S14, S15, S16, S17, S18, S19, S20, S22, S23, S24, S25, S26: TL3342F160QG; SW_SPST_TL3342
U1: MCP73831-2-OT; SOT-23-5
U2: XC6220B331; SOT-23-5
U3: CH340C; SOIC-16_3.9x9.9mm_P1.27mm
U4: USBLC6-2P6; SOT-666
U5: LIS3DHTR; XDCR_LIS3DHTR; PARTREV 2
U6: TSSP77038; Heimdall vertical
U7: ESP32-PICO-D4; QFN-48-1EP_7x7mm_P0.5mm_EP5.3x5.3mm_ThermalVias_MR
U8: AP2112K-3.3; SOT-23-5

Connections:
+3.3V: C6.1, C7.2, C8.2, C10.1, C11.1, C13.2, C14.1, C17.1, C21.2, C22.1, Q3.2 (S), Q4.2 (S), Q5.2 (S), R20.2, R22.2, R25.2, R26.2, R37.2, U2.5 (VOUT), U5.1 (VDD_IO), U5.8 (CS), U5.14 (VDD), U7.1 (VDDA), U7.3 (VDDA3P3), U7.4 (VDDA3P3), U7.19 (VDD3P3_RTC), U7.37 (VDD3P3_CPU), U7.43 (VDDA), U7.46 (VDDA)
+BATT: C5.2, J3.1, J4.2, Q1.3 (D), U1.3 (VBAT)
+VSW: C9.1, C25.2, J2.7, J2.8, J2.9, J2.40, J2.41, J2.42 (Pin_41), Q4.3 (D), R11.2, R12.2, R19.1, R30.1
/D+_1: J1.A6 (D+), J1.B6 (D+), U4.1 (I/O1)
/D+_2: U3.5 (UD+), U4.6 (I/O1)
/D-_1: J1.A7 (D-), J1.B7 (D-), U4.3 (I/O2)
/D-_2: U3.6 (UD-), U4.4 (I/O2)
/LCD_NRST: J2.10, R19.2
/LEDA#1: J2.2, R17.1
/LEDA#2: J2.3, R15.1
/LEDA#3: J2.4, R18.1
/LEDA#4: J2.5, R16.1
/TP_NRST: C23.2, J2.47, R30.2
/VUSB_RAW: F1.1, J1.A4 (VBUS), J1.A9 (VBUS), J1.B4 (VBUS), J1.B9 (VBUS), U4.5 (VBUS)
ACC_INT: U5.11 (INT1), U7.20 (IO13)
ADC_BAT: C20.1, R23.1, R24.2, U7.5 (SENSOR_VP)
CRG_STAT: R39.1, U1.1 (STAT), U7.42 (IO21)
DTR: Q2.4 (E2), R13.1, U3.13 (~DTR)
ESP_EN: C15.2, Q2.6 (C1), R22.1, S26.2, U7.9 (EN)
GND: C1.1, C2.2, C3.1, C4.2, C5.1, C6.2, C7.1, C8.1, C9.2, C10.2, C11.2, C12.2, C13.1, C14.2, C15.1, C16.1, C17.2, C18.1, C19.1, C20.2, C21.1, C22.2, C23.1, C24.2, C25.1, D2.1 (K), D5.1 (K), H1.1, H2.1, H3.1, H4.1, H5.1, J1.A1 (GND), J1.A8 (SBU1), J1.A12 (GND), J1.B1 (GND), J1.B8 (SBU2), J1.B12 (GND), J1.S1 (SHIELD), J2.1, J2.6, J2.11, J2.12, J2.13, J2.14, J2.15, J2.16, J2.17, J2.18, J2.19, J2.20, J2.21, J2.22, J2.23, J2.24, J2.25, J2.26, J2.27, J2.28, J2.29, J2.30, J2.31, J2.32, J2.43, J2.48, J2.49, J2.50, J2.MP, J3.2, J4.1, R6.1, R7.1, R8.1, R9.1, R24.1, R31.2, R32.2, R33.2, R34.2, R35.2, R38.1, S26.1, U1.2 (VSS), U2.2 (GND), U3.1 (GND), U4.2 (GND), U5.5 (GND), U5.10 (RES), U5.12 (GND), U6.1 (GND), U6.4 (GND), U7.49 (GND), U8.2 (GND)
IO0: Q2.3 (C2), R37.1, U7.23 (IO0)
IR_LED: R27.2, U7.13 (IO33)
IR_RX: R40.1, U7.21 (IO15)
IR_VCC: C12.1, U6.3 (Vs), U7.14 (IO25)
LCD_BL: R29.2, U7.24 (IO4)
LCD_CS: J2.38, U7.34 (IO5)
LCD_DC: J2.36, U7.28 (SD2/IO9)
LCD_EN: R28.2, U7.29 (SD3/IO10)
LCD_MOSI: J2.34, U7.36 (IO23)
LCD_SCK: J2.37, U7.35 (IO18)
unnamed: AE1.1 (A), C19.2, R36.1
unnamed: D1.1 (K), Q1.2 (S), R10.2, R23.2
unnamed: D2.2 (A), R21.2
unnamed: D3.2 (A), U7.22 (IO2)
unnamed: D3.1 (K), R38.2
unnamed: D4.1 (K), R39.2
unnamed: D5.2 (A), R1.1
unnamed: J1.A5 (CC1), R9.2
unnamed: J1.B5 (CC2), R7.2
unnamed: Q2.2 (B1), R13.2
unnamed: Q2.5 (B2), R14.2
unnamed: C16.2, Q3.3 (D), R15.2, R16.2, R17.2, R18.2
unnamed: Q3.1 (G), R25.1, R29.1
unnamed: Q4.1 (G), R26.1, R28.1
unnamed: Q5.3 (D), R1.2, R21.1
unnamed: Q5.1 (G), R20.1, R27.1
unnamed: R8.2, U1.5 (PROG)
unnamed: C3.2, R10.1, U2.1 (VIN), U2.3 (CE)
unnamed: C4.1, C24.1, U3.4 (V3), U3.16 (VCC), U8.5 (VOUT)
unnamed: R40.2, U6.2 (OUT)
unnamed: C18.2, R36.2, U7.2 (LNA_IN)
RTS: Q2.1 (E1), R14.1, U3.14 (~RTS)
SCL: J2.44, R11.1, U5.4 (SCL/SPC), U7.39 (IO22)
SDA: J2.45, R12.1, U5.6 (SDA/SDI/SDO), U7.38 (IO19)
SW_1: S1.1, S6.1, S11.1, S16.1, U7.12 (IO32)
SW_2: S2.1, S7.1, S12.1, S17.1, S22.1, U7.15 (IO26)
SW_3: S3.1, S8.1, S13.1, S18.1, S23.1, U7.16 (IO27)
SW_4: S4.1, S9.1, S14.1, S19.1, S24.1, U7.17 (IO14)
SW_5: S5.1, S10.1, S15.1, S20.1, S25.1, U7.18 (IO12)
SW_A: R31.1, S1.2, S2.2, S3.2, S4.2, S5.2, U7.6 (SENSOR_CAPP)
SW_B: R32.1, S6.2, S7.2, S8.2, S9.2, S10.2, U7.7 (SENSOR_CAPN)
SW_C: R33.1, S11.2, S12.2, S13.2, S14.2, S15.2, U7.8 (SENSOR_VN)
SW_D: R34.1, S16.2, S17.2, S18.2, S19.2, S20.2, U7.10 (IO34)
SW_E: R35.1, S22.2, S23.2, S24.2, S25.2, U7.11 (IO35)
USB_RXD: U3.2 (TXD), U7.40 (U0RXD/IO3)
USB_TXD: U3.3 (RXD), U7.41 (U0TXD/IO1)
VBUS: C1.2, C2.1, D1.2 (A), D4.2 (A), F1.2, Q1.1 (G), R6.2, U1.4 (VDD), U8.1 (VIN), U8.3 (EN)

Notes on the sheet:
DB6
ACC I2C address: 0x19
DB11
DB14
IM2
DB10
Display Interface
STAT Shutdown - High Z No Battery Present - High Z Constant Voltage - Low Charge Complete - High
LEDA
DB0
GND
DB16
TP_RES
TP_IRQ
LEDK
IM1
IOVCC
- Pull-Down resistors needed for ext1 interrupt
~{RESET}
ESP32
RTC GPIO: 0,2,4,12-15,25-27,32-39 ext0: - single RTC_GPIO as wakeup source ext1: - multiple RTC_GPIOs as wakeup source - either any pin high or all pins low - internal Pull-ups /Pull-downs disabled
IM3
DB5
Possible Replacement: LR4054-T
Extra Parts
USB-Serial Bridge
Charge current: I_CHG = 1000 / R_PROG 1000 / 3kOhm = 333mA
DB17
TP_SDA
DB7
DB12
DB1
DOTCLK
~{WR_RS}
Infrared TX / RX
SDI
DB13
DB4
Boot Mode Configuration: Pin Default Boot Download GPIO0 1 1 0 U0TXD 1 1 x GPIO2 0 x 0 GPIO4 0 x x MTDO 1 x x GPIO5 1 1 x If U0TXD, GPIO2, GPIO5 are floating, GPIO0 determines boot mode
Touch I2C address: 0x38

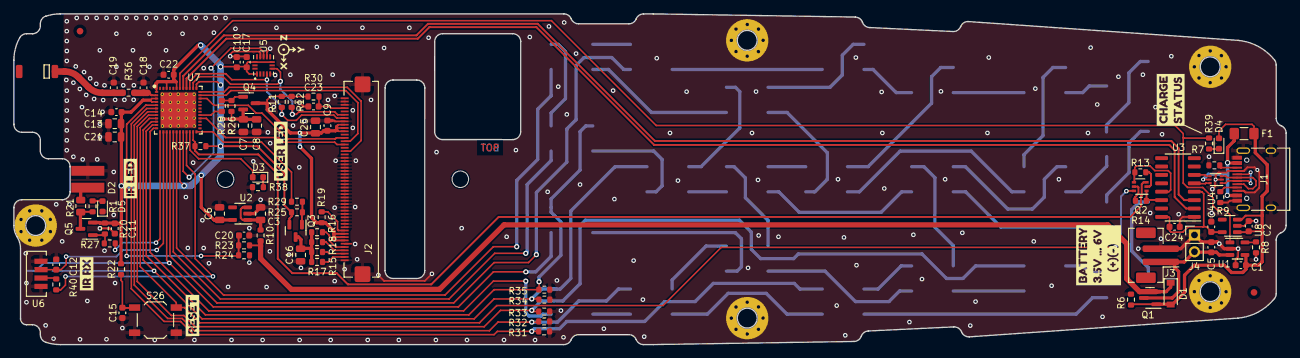
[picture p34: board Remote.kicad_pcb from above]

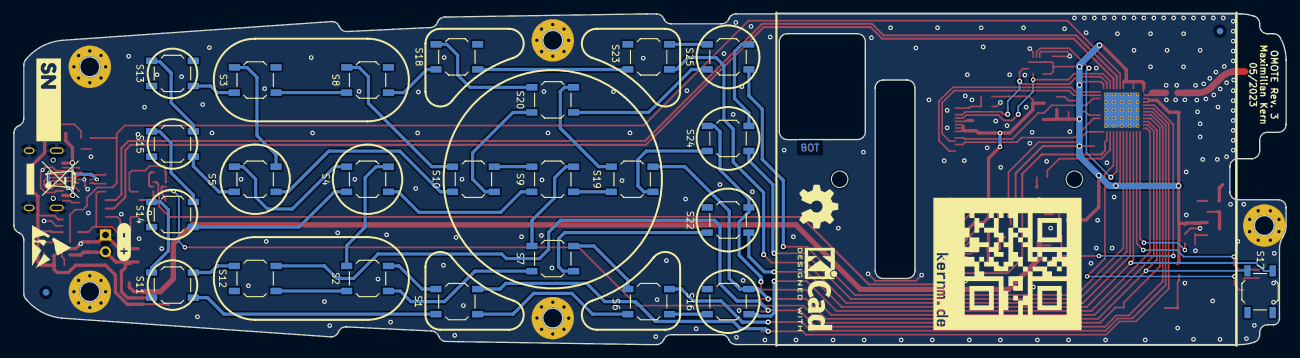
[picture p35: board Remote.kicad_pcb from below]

Board: 2 copper layers, 192.4 x 50.0 mm, 133 parts (29 on the bottom side), 67 nets.

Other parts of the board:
kibuzzard-63D97EAF: G***; kibuzzard-63D97EAF
kibuzzard-64A91BF0: G***; kibuzzard-64A91BF0
kibuzzard-64A91C1C: G***; kibuzzard-64A91C1C
kibuzzard-64A91C24: G***; kibuzzard-64A91C24
kibuzzard-643EE5A3: G***; kibuzzard-643EE5A3
kibuzzard-643EE5B9: G***; kibuzzard-643EE5B9
kibuzzard-643EE8B3: G***; kibuzzard-643EE8B3
kibuzzard-643EE23D: G***; kibuzzard-643EE23D
kibuzzard-643EE46C: G***; kibuzzard-643EE46C
kibuzzard-643EE532: G***; kibuzzard-643EE532
kibuzzard-643EE600: G***; kibuzzard-643EE600
kibuzzard-644014FA: G***; kibuzzard-644014FA

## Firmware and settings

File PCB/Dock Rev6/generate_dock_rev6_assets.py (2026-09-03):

#!/usr/bin/env python3
"""Generate the self-contained Dock Rev6 KiCad libraries and custom STEP models."""

from __future__ import annotations

import json
import shutil
import sys
import uuid
from pathlib import Path


ROOT = Path(__file__).resolve().parent
LIB = ROOT / "project_libraries"
PRETTY = LIB / "footprints" / "DockRev6.pretty"
MODELS = LIB / "3D-models"
SYMBOLS = LIB / "symbols"

KICAD = Path("/Applications/KiCad/KiCad.app/Contents/SharedSupport")
FP_STD = KICAD / "footprints"
MODEL_STD = KICAD / "3dmodels"
REMOTE_REV6 = ROOT.parent / "Revision 6" / "project_libraries"


def uid() -> str:
    return str(uuid.uuid4())


def write(path: Path, text: str) -> None:
    path.parent.mkdir(parents=True, exist_ok=True)
    path.write_text(text, encoding="utf-8")


def localize_footprint(src: Path, dst_name: str, model_name: str, description: str) -> None:
    text = src.read_text(encoding="utf-8")
    first = text.splitlines()[0]
    old_name = first.split('"')[1]
    text = text.replace(f'(footprint "{old_name}"', f'(footprint "{dst_name}"', 1)
    lines = text.splitlines()
    for index, line in enumerate(lines):
        if line.lstrip().startswith("(descr "):
            indent = line[: len(line) - len(line.lstrip())]
            lines[index] = f'{indent}(descr "{description}")'
            break
    text = "\n".join(lines) + "\n"
    # Replace whichever stock model was supplied with the self-contained project model.
    start = text.find("\t(model ")
    if start < 0:
        start = text.find("  (model ")
    if start >= 0:
        q1 = text.find('"', start)
        q2 = text.find('"', q1 + 1)
        text = text[: q1 + 1] + f"${{KIPRJMOD}}/project_libraries/3D-models/{model_name}" + text[q2:]
    write(PRETTY / f"{dst_name}.kicad_mod", text)


def fp_header(name: str, reference: str, description: str, tags: str) -> list[str]:
    return [
        f'(footprint "{name}"',
        '\t(version 20240108)',
        '\t(generator "pcbnew")',
        '\t(generator_version "10.0")',
        '\t(layer "F.Cu")',
        f'\t(descr "{description}")',
        f'\t(tags "{tags}")',
        f'\t(property "Reference" "{reference}" (at 0 -14 0) (layer "F.SilkS") (uuid "{uid()}")',
        '\t\t(effects (font (size 1 1) (thickness 0.15))))',
        f'\t(property "Value" "{name}" (at 0 14 0) (layer "F.Fab") (uuid "{uid()}")',
        '\t\t(effects (font (size 1 1) (thickness 0.15))))',
        f'\t(property "Footprint" "" (at 0 0 0) (unlocked yes) (layer "F.Fab") (hide yes) (uuid "{uid()}")',
        '\t\t(effects (font (size 1.27 1.27))))',
        f'\t(property "Datasheet" "" (at 0 0 0) (unlocked yes) (layer "F.Fab") (hide yes) (uuid "{uid()}")',
        '\t\t(effects (font (size 1.27 1.27))))',
        f'\t(property "Description" "{description}" (at 0 0 0) (unlocked yes) (layer "F.Fab") (hide yes) (uuid "{uid()}")',
        '\t\t(effects (font (size 1.27 1.27))))',
        '\t(attr through_hole)',
    ]


def fp_line(x1: float, y1: float, x2: float, y2: float, layer: str, width: float) -> str:
    return (
        f'\t(fp_line (start {x1:g} {y1:g}) (end {x2:g} {y2:g}) '
        f'(stroke (width {width:g}) (type solid)) (layer "{layer}") (uuid "{uid()}"))'
    )


def fp_text(text: str, x: float, y: float, layer: str = "F.Fab", size: float = 0.65) -> str:
    return (
        f'\t(fp_text user "{text}" (at {x:g} {y:g}) (layer "{layer}") (uuid "{uid()}") '
        f'(effects (font (size {size:g} {size:g}) (thickness 0.1))))'
    )


def pad(number: int | str, x: float, y: float, pin1: bool = False) -> str:
    shape = "rect" if pin1 else "circle"
    return (
        f'\t(pad "{number}" thru_hole {shape} (at {x:g} {y:g}) (size 1.9 1.9) '
        f'(drill 1) (layers "*.Cu" "*.Mask") (remove_unused_layers no) (uuid "{uid()}"))'
    )


def model_block(
    filename: str,
    offset: tuple[float, float, float] = (0, 0, 0),
    rotate: tuple[float, float, float] = (0, 0, 0),
) -> list[str]:
    ox, oy, oz = offset
    rx, ry, rz = rotate
    model_path = filename if filename.startswith("${") else f"${{KIPRJMOD}}/project_libraries/3D-models/{filename}"
    return [
        f'\t(model "{model_path}"',
        f'\t\t(offset (xyz {ox:g} {oy:g} {oz:g}))',
        '\t\t(scale (xyz 1 1 1))',
        f'\t\t(rotate (xyz {rx:g} {ry:g} {rz:g}))',
        '\t)',
    ]


def make_esp_footprint() -> None:
    name = "ESP32-C3_SuperMini_Header_2x08_P2.54mm"
    lines = fp_header(
        name,
        "U",
        "Generic ESP32-C3 Super Mini, 18x22.52mm, two 1x8 2.54mm header rows",
        "ESP32 C3 Super Mini module header 2.54mm",
    )
    # Board outline and USB overhang.
    for layer, width in (("F.SilkS", 0.15), ("F.Fab", 0.1), ("F.CrtYd", 0.05)):
        extra = 0.5 if layer == "F.CrtYd" else 0
        x0, x1 = -9 - extra, 9 + extra
        y0, y1 = -11.26 - extra, 11.26 + extra
        lines += [
            fp_line(x0, y0, x1, y0, layer, width), fp_line(x1, y0, x1, y1, layer, width),
            fp_line(x1, y1, x0, y1, layer, width), fp_line(x0, y1, x0, y0, layer, width),
        ]
    lines += [fp_line(-4.5, -11.26, 4.5, -11.26, "F.SilkS", 0.35)]
    # Use signal names as pad numbers to avoid inventing an ambiguous 1-16 numbering scheme.
    # Order is exactly the supplied module image, with USB-C at negative Y.
    left_names = ["5V", "GND", "3V3", "4", "3", "2", "1", "0"]
    right_names = ["5", "6", "7", "8", "9", "10", "20", "21"]
    aliases = {
        "4": "GPIO4/SCK/A4", "3": "GPIO3/A3", "2": "GPIO2/A2", "1": "GPIO1/A1", "0": "GPIO0/A0",
        "5": "GPIO5/MISO/A5", "6": "GPIO6/MOSI", "7": "GPIO7/SS", "8": "GPIO8/SDA",
        "9": "GPIO9/SCL", "10": "GPIO10", "20": "GPIO20/RX", "21": "GPIO21/TX",
    }
    ys = [-8.89 + 2.54 * i for i in range(8)]
    for index, (signal, y) in enumerate(zip(left_names, ys)):
        lines.append(pad(signal, -7.62, y, index == 0))
        label = signal if signal in ("5V", "GND", "3V3") else aliases[signal]
        lines.append(fp_text(label, -5.55, y, size=0.52))
    for signal, y in zip(right_names, ys):
        lines.append(pad(signal, 7.62, y))
        lines.append(fp_text(aliases[signal], 5.25, y, size=0.48))
    lines += [fp_text("ANTENNA KEEPOUT", 0, 9.0, "F.SilkS", 0.8)]
    # The supplied STEP uses a corner-based, landscape coordinate system.
    # Rotate it into the footprint's portrait orientation and centre its PCB.
    lines += model_block("ESP32-C3_SuperMini.step", offset=(-9, 11.26, 2.24), rotate=(0, 0, 90))
    lines += model_block("ESP32-C3_SuperMini_2x08_Header.step")
    lines.append(")")
    write(PRETTY / f"{name}.kicad_mod", "\n".join(lines) + "\n")


def make_cc1101_footprint() -> None:
    name = "CC1101_433MHz_Coil_Module_2x04_P2.54mm"
    lines = fp_header(
        name,
        "U",
        "CC1101 433MHz module with spring/coil antenna, 28x15mm PCB and 2x4 2.54mm header",
        "CC1101 433MHz RF transceiver spring coil antenna module",
    )
    # Origin is the 2x4 header centre; module body extends to the right.
    for layer, width in (("F.SilkS", 0.15), ("F.Fab", 0.1), ("F.CrtYd", 0.05)):
        # Courtyard includes both the PCB and the off-board spring antenna as one closed shape.
        if layer == "F.CrtYd":
            x0, x1, y0, y1 = -3.3, 44.0, -8.0, 8.0
        else:
            x0, x1, y0, y1 = -2.8, 25.2, -7.5, 7.5
        lines += [
            fp_line(x0, y0, x1, y0, layer, width), fp_line(x1, y0, x1, y1, layer, width),
            fp_line(x1, y1, x0, y1, layer, width), fp_line(x0, y1, x0, y0, layer, width),
        ]
    pin_names = ["GND", "VCC", "GDO0", "CSN", "SCK", "MOSI", "MISO/GDO1", "GDO2"]
    for row, y in enumerate((-3.81, -1.27, 1.27, 3.81)):
        left_num, right_num = row * 2 + 1, row * 2 + 2
        lines.append(pad(left_num, -1.27, y, left_num == 1))
        lines.append(pad(right_num, 1.27, y))
        lines.append(fp_text(pin_names[left_num - 1], 4.2, y - 0.35, size=0.5))
        lines.append(fp_text(pin_names[right_num - 1], 4.2, y + 0.35, size=0.5))
    lines += [
        fp_text("SPRING ANTENNA ->", 17.5, 0, "F.SilkS", 0.8),
    ]
    lines += model_block("CC1101_433MHz_Coil_Module.step")
    lines.append(")")
    write(PRETTY / f"{name}.kicad_mod", "\n".join(lines) + "\n")


def make_symbols() -> None:
    symbols = [
        ("ESP32-C3_SuperMini", "U", ["5V", "GND", "3V3", "4", "3", "2", "1", "0", "5", "6", "7", "8", "9", "10", "20", "21"], "DockRev6:ESP32-C3_SuperMini_Header_2x08_P2.54mm"),
        ("CC1101_433MHz_Coil", "U", ["GND", "VCC", "GDO0", "CSN", "SCK", "MOSI", "MISO/GDO1", "GDO2"], "DockRev6:CC1101_433MHz_Coil_Module_2x04_P2.54mm"),
        ("MHL512IR059CRT", "D", ["K", "A"], "DockRev6:LED_5mm_Side_Mount_C405273"),
        # FUXINSEMI C908265 physical order: 1=S1, 2=D1, 3=S2,
        # 4=G2, 5=D2, 6=G1. Pins 2 and 5 are the common drains.
        ("FS8205A", "Q", ["S1", "D1", "S2", "G2", "D2", "G1"], "DockRev6:FS8205A_SOT-23-6"),
        ("HX-XH2.54-2PZZ", "J", ["1", "2"], "DockRev6:HX-XH2.54-2PZZ_C42391660"),
        ("SW_6x6x5H", "SW", ["1", "2"], "DockRev6:SW_6x6x5H_THT"),
        ("LED_5mm_Green", "D", ["K", "A"], "DockRev6:LED_5mm_Green_THT"),
    ]
    out = ['(kicad_symbol_lib (version 20231120) (generator "kicad_symbol_editor")']
    for name, ref, pins, footprint in symbols:
        height = max(7.62, (len(pins) // 2 + 1) * 2.54)
        top = height / 2
        # Give module pin names real breathing room. The ESP32 aliases are much
        # longer than ordinary IC pin names, and the CC1101 also needs more than
        # the generic 10.16 mm-wide body used by the small discrete symbols.
        if name == "ESP32-C3_SuperMini":
            half_width = 15.24
        elif name == "CC1101_433MHz_Coil":
            half_width = 10.16
        else:
            half_width = 5.08
        pin_x = half_width + 2.54
        out += [
            f'\t(symbol "{name}"',
            '\t\t(pin_names (offset 1.016))',
            '\t\t(exclude_from_sim no) (in_bom yes) (on_board yes)',
            f'\t\t(property "Reference" "{ref}" (at 0 {top + 2.54:g} 0) (effects (font (size 1.27 1.27))))',
            f'\t\t(property "Value" "{name}" (at 0 {-top - 2.54:g} 0) (effects (font (size 1.27 1.27))))',
            f'\t\t(property "Footprint" "{footprint}" (at 0 0 0) (hide yes) (effects (font (size 1.27 1.27))))',
            '\t\t(property "Datasheet" "" (at 0 0 0) (hide yes) (effects (font (size 1.27 1.27))))',
            f'\t\t(property "Description" "Dock Rev6 project component: {name}" (at 0 0 0) (hide yes) (effects (font (size 1.27 1.27))))',
            f'\t\t(symbol "{name}_0_1" (rectangle (start {-half_width:g} {top:g}) (end {half_width:g} {-top:g}) (stroke (width 0) (type default)) (fill (type background))))',
            f'\t\t(symbol "{name}_1_1"',
        ]
        left_count = (len(pins) + 1) // 2
        right_count = len(pins) - left_count
        for index, pin_name in enumerate(pins[:left_count], 1):
            y = (left_count - 1) * 1.27 - (index - 1) * 2.54
            is_supermini = name == "ESP32-C3_SuperMini"
            if name in ("HX-XH2.54-2PZZ", "LED_5mm_Green", "MHL512IR059CRT", "SW_6x6x5H"):
                etype = "passive"
            elif name == "FS8205A":
                etype = "input" if pin_name in ("G1", "G2") else "passive"
            elif is_supermini and pin_name == "3V3":
                etype = "power_out"
            else:
                etype = "power_in" if pin_name in ("GND", "VCC", "3V3", "5V") else "bidirectional"
            pin_number = pin_name if is_supermini else str(index)
            supermini_aliases = {"4": "GPIO4/SCK/A4", "3": "GPIO3/A3", "2": "GPIO2/A2", "1": "GPIO1/A1", "0": "GPIO0/A0"}
            display_name = pin_name if not is_supermini or pin_name in ("5V", "GND", "3V3") else supermini_aliases[pin_name]
            out.append(f'\t\t\t(pin {etype} line (at {-pin_x:g} {y:g} 0) (length 2.54) (name "{display_name}" (effects (font (size 1.27 1.27)))) (number "{pin_number}" (effects (font (size 1.27 1.27)))))')
        for rindex, pin_name in enumerate(pins[left_count:], left_count + 1):
            local = rindex - left_count - 1
            y = (right_count - 1) * 1.27 - local * 2.54
            is_supermini = name == "ESP32-C3_SuperMini"
            if name in ("HX-XH2.54-2PZZ", "LED_5mm_Green", "MHL512IR059CRT", "SW_6x6x5H"):
                etype = "passive"
            elif name == "FS8205A":
                etype = "input" if pin_name in ("G1", "G2") else "passive"
            elif is_supermini and pin_name == "3V3":
                etype = "power_out"
            else:
                etype = "power_in" if pin_name in ("GND", "VCC", "3V3", "5V") else "bidirectional"
            pin_number = pin_name if is_supermini else str(rindex)
            supermini_aliases = {"5": "GPIO5/MISO/A5", "6": "GPIO6/MOSI", "7": "GPIO7/SS", "8": "GPIO8/SDA", "9": "GPIO9/SCL", "10": "GPIO10", "20": "GPIO20/RX", "21": "GPIO21/TX"}
            display_name = supermini_aliases[pin_name] if is_supermini else pin_name
            out.append(f'\t\t\t(pin {etype} line (at {pin_x:g} {y:g} 180) (length 2.54) (name "{display_name}" (effects (font (size 1.27 1.27)))) (number "{pin_number}" (effects (font (size 1.27 1.27)))))')
        out += ['\t\t)', '\t)']
    out.append(')')
    write(SYMBOLS / "DockRev6.kicad_sym", "\n".join(out) + "\n")


def make_models() -> None:
    try:
        import cadquery as cq
        from cadquery import exporters
    except ImportError as exc:
        raise SystemExit("CadQuery is required to generate the two custom STEP models") from exc

    def colored_box(assy, name, size, center, color):
        x, y, z = size
        cx, cy, cz = center
        solid = cq.Workplane("XY").box(x, y, z).translate((cx, cy, cz))
        assy.add(solid, name=name, color=cq.Color(*color))

    # ESP32-C3_SuperMini.step is the owner's supplied model and is intentionally
    # not regenerated. Keeping it project-local makes KiCad independent of the
    # original Downloads path.
    if not (MODELS / "ESP32-C3_SuperMini.step").is_file():
        raise SystemExit("Missing supplied project model: ESP32-C3_SuperMini.step")

    # CC1101 433MHz spring antenna module. Origin matches the header centre in its footprint.
    cc = cq.Assembly(name="CC1101 433MHz Coil Module")
    cc_board = cq.Workplane("XY").box(28, 15, 1.0).translate((11.2, 0, 0.5))
    # Common module has two mechanical holes near the antenna end.
    for y in (-4.9, 4.9):
        cc_board = cc_board.faces(">Z").workplane().pushPoints([(21.0, y)]).hole(2.8)
    cc.add(cc_board, name="PCB", color=cq.Color(0.03, 0.18, 0.38))
    colored_box(cc, "CC1101", (6.2, 6.2, 1.0), (9.2, 0, 1.5), (0.06, 0.06, 0.06))
    colored_box(cc, "Crystal", (4.0, 2.5, 1.4), (15.5, -3.6, 1.7), (0.72, 0.72, 0.70))
    for index, (cx, cy) in enumerate(((15.0, 3.4), (18.2, 3.4), (18.5, 0), (14.8, -0.4))):
        colored_box(cc, f"RF component {index}", (2.0, 1.2, 0.8), (cx, cy, 1.4), (0.12, 0.12, 0.12))
    for row, y in enumerate((-3.81, -1.27, 1.27, 3.81)):
        for x in (-1.27, 1.27):
            colored_box(cc, f"Header pin {row} {x}", (0.64, 0.64, 7.0), (x, y, 0.5), (0.78, 0.62, 0.18))
            colored_box(cc, f"Header body {row} {x}", (2.45, 2.45, 2.5), (x, y, 2.25), (0.06, 0.06, 0.06))
    # Gold antenna launch pad and a physical helical 433MHz coil extending from the module.
    colored_box(cc, "Antenna pad", (3.5, 4.0, 0.25), (23.0, 0, 1.125), (0.82, 0.64, 0.12))
    helix = cq.Wire.makeHelix(1.8, 18.0, 2.3, cq.Vector(25.0, 0, 3.1), cq.Vector(1, 0, 0))
    coil = cq.Workplane("YZ", origin=(25.0, 0, 3.1)).circle(0.28).sweep(helix)
    cc.add(coil, name="433MHz spring antenna", color=cq.Color(0.65, 0.47, 0.18))
    cc.save(str(MODELS / "CC1101_433MHz_Coil_Module.step"))


def make_project_files() -> None:
    # Preserve the current KiCad 10 project settings while removing Rev6-specific board variants.
    source_pro = ROOT.parent / "Revision 6" / "OpenRemote.kicad_pro"
    project = json.loads(source_pro.read_text(encoding="utf-8"))
    project.setdefault("meta", {})["filename"] = "Dock Rev6.kicad_pro"
    project["meta"]["version"] = 1
    if isinstance(project.get("board"), dict):
        project["board"]["3dviewports"] = []
    project["net_settings"] = {"classes": [], "meta": {"version": 3}}
    write(ROOT / "Dock Rev6.kicad_pro", json.dumps(project, indent=2) + "\n")

    write(ROOT / "fp-lib-table", '''(fp_lib_table
  (version 7)
  (lib (name "DockRev6")(type "KiCad")(uri "${KIPRJMOD}/project_libraries/footprints/DockRev6.pretty")(options "")(descr "Dock Rev6 self-contained footprint library"))
  (lib (name "Capacitor_SMD")(type "KiCad")(uri "${KICAD10_FOOTPRINT_DIR}/Capacitor_SMD.pretty")(options "")(descr "KiCad standard SMD capacitors"))
  (lib (name "Capacitor_THT")(type "KiCad")(uri "${KICAD10_FOOTPRINT_DIR}/Capacitor_THT.pretty")(options "")(descr "KiCad standard through-hole capacitors"))
  (lib (name "Resistor_SMD")(type "KiCad")(uri "${KICAD10_FOOTPRINT_DIR}/Resistor_SMD.pretty")(options "")(descr "KiCad standard SMD resistors"))
  (lib (name "Resistor_THT")(type "KiCad")(uri "${KICAD10_FOOTPRINT_DIR}/Resistor_THT.pretty")(options "")(descr "KiCad standard through-hole resistors"))
)
''')
    write(ROOT / "sym-lib-table", '''(sym_lib_table
  (version 7)
  (lib (name "DockRev6")(type "KiCad")(uri "${KIPRJMOD}/project_libraries/symbols/DockRev6.kicad_sym")(options "")(descr "Dock Rev6 project symbols"))
  (lib (name "Device")(type "KiCad")(uri "${KICAD10_SYMBOL_DIR}/Device.kicad_sym")(options "")(descr "KiCad standard device symbols"))
  (lib (name "power")(type "KiCad")(uri "${KICAD10_SYMBOL_DIR}/power.kicad_sym")(options "")(descr "KiCad standard power symbols"))
)
''')
    schematic_path = ROOT / "Dock Rev6.kicad_sch"
    if not schematic_path.exists():
        write(schematic_path, f'''(kicad_sch
  (version 20231120)
  (generator "eeschema")
  (generator_version "10.0")
  (uuid "{uid()}")
  (paper "A4")
  (title_block (title "OpenRemote Charging Dock") (date "25 Aug 2026") (rev "6") (company "OpenRemote"))
  (lib_symbols)
  (sheet_instances (path "/" (page "1")))
  (embedded_fonts no)
)
''')


def make_readme() -> None:
    write(ROOT / "README.md", '''# OpenRemote Dock Rev6 KiCad Project

This is a self-contained KiCad 10 project starter for the OpenRemote Rev6 charging dock.

## Included footprints and 3D models

| Library footprint | Intended hardware | Interface / package |
|---|---|---|
| `ESP32-C3_SuperMini_Header_2x08_P2.54mm` | ESP32-C3 Super Mini shown by the owner | Two 1x8 headers, 2.54 mm pitch; owner-supplied STEP model |
| `CC1101_433MHz_Coil_Module_2x04_P2.54mm` | 28x15 mm CC1101 433 MHz module, spring antenna version | 2x4 header, 2.54 mm pitch |
| `LED_5mm_Side_Mount_C405273` | Meihua MHL512IR059CRT IR LED, LCSC C405273 | THT, 5 mm, horizontal/side mounting |
| `FS8205A_SOT-23-6` | FUXINSEMI FS8205A, LCSC C908265 | SOT-23-6 |
| `HX-XH2.54-2PZZ_C42391660` | hanxia HX-XH2.54-2PZZ, LCSC C42391660 | Vertical shrouded 1x2 male header; vendor land pattern is 2.50 mm pitch |
| `SW_6x6x5H_THT` | 6x6 mm tactile switch, 5 mm body height | Four-pin THT |
| `LED_5mm_Green_THT` | Standard green 5 mm LED | THT, 2.54 mm pitch |

The ESP32 model is the owner's supplied `esp32 c3 supermini.step`, copied into the project as `ESP32-C3_SuperMini.step`. All STEP files are project-local, so no Downloads or global KiCad 3D-model path is required.

## Important sourcing notes

- The ESP module follows the owner's supplied **16-pin ESP32-C3 Super Mini** image: 18x22.52 mm with two 1x8, 2.54 mm header rows. It does not use the different 18-pin Waveshare C3-Zero footprint from the earlier retail link.
- J1 is the exact hanxia HX-XH2.54-2PZZ sold as LCSC C42391660. LCSC describes it as 2.54 mm, but its manufacturer-linked EasyEDA land pattern uses 2.50 mm pad pitch, 1.0 mm drills, and a 7.5 x 5.9 mm shrouded body; the project follows that land pattern.
- CC1101 clone modules vary. This footprint follows the common 28x15 mm, 2x4 2.54 mm module and the pin order shown in the provided image. Check the delivered module before ordering the PCB.
- `Dock Rev6.kicad_pcb` now uses the Fusion handoff geometry: a 45x60 mm main body, 15 mm front/rear tongues, 92 mm overall length, and smooth blends. The tongues were narrowed from the nominal handoff width to maintain at least 1 mm clearance from the existing lid screw receivers.
- Four 3.3 mm NPTH M3 mounting holes are on an exact 37x52 mm pattern at dock X/Z `(+/-18.5, +6)` and `(+/-18.5, -46)`. Each hole has an R4 mm all-copper keepout and an 8 mm head-clearance reference circle.
- The matching Fusion base lid has four 7.5 mm OD bosses at those same centres. Each boss has a 2.55 mm blind pilot, an 8.0 mm PCB seating plane, and 3.4 mm thread engagement for an M3x5 screw through this 1.6 mm board. The original pre-boss lid body is retained hidden for rollback.

## Pin order

CC1101 pads are numbered by rows as shown in the supplied diagram: `1 GND`, `2 VCC`, `3 GDO0`, `4 CSN`, `5 SCK`, `6 MOSI`, `7 MISO/GDO1`, `8 GDO2`.

ESP32-C3 Super Mini pad numbers use the printed signal names directly. USB-C is at the top: left row `5V`, `GND`, `3V3`, `GPIO4/SCK/A4`, `GPIO3/A3`, `GPIO2/A2`, `GPIO1/A1`, `GPIO0/A0`; right row `GPIO5/MISO/A5`, `GPIO6/MOSI`, `GPIO7/SS`, `GPIO8/SDA`, `GPIO9/SCL`, `GPIO10`, `GPIO20/RX`, `GPIO21/TX`.

## Electrical design
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

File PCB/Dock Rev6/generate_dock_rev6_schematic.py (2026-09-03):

#!/usr/bin/env python3
"""Generate the Dock Rev6 controller schematic.

Requires kiutils. The resulting file is upgraded by KiCad after generation so
the checked-in schematic always uses the locally installed KiCad file format.
"""

from __future__ import annotations

from copy import deepcopy
from pathlib import Path
from uuid import uuid4

from kiutils.items.common import Effects, Font, PageSettings, Position, Property, Stroke, TitleBlock
from kiutils.items.schitems import (
    Connection,
    HierarchicalSheetInstance,
    LocalLabel,
    NoConnect,
    SchematicSymbol,
    SymbolProjectInstance,
    SymbolProjectPath,
    Text,
)
from kiutils.schematic import Schematic
from kiutils.symbol import Symbol, SymbolLib


HERE = Path(__file__).resolve().parent
OUT = HERE / "Dock Rev6.kicad_sch"
CUSTOM_LIB = HERE / "project_libraries" / "symbols" / "DockRev6.kicad_sym"
KICAD_SYMBOLS = Path("/Applications/KiCad/KiCad.app/Contents/SharedSupport/symbols")
PROJECT_NAME = "Dock Rev6"


def uid() -> str:
    return str(uuid4())


def snap(value: float) -> float:
    """Snap schematic origins to KiCad's 50 mil connection grid."""
    return round(value / 1.27) * 1.27


def font_effects(hide: bool = False, size: float = 1.27, bold: bool = False) -> Effects:
    return Effects(font=Font(width=size, height=size, bold=bold), hide=hide)


def property_at(key: str, value: str, x: float, y: float, hide: bool = False) -> Property:
    return Property(
        key=key,
        value=value,
        position=Position(X=x, Y=y, angle=0),
        effects=font_effects(hide=hide),
    )


def placed_property(source: Symbol, key: str, value: str, x: float, y: float, hide: bool) -> Property:
    template = next((p for p in source.properties if p.key == key), None)
    if template is None:
        return property_at(key, value, x, y, hide)
    effects = deepcopy(template.effects) if template.effects is not None else font_effects()
    effects.hide = hide
    return Property(
        key=key,
        value=value,
        position=Position(
            X=x + template.position.X,
            Y=y - template.position.Y,
            angle=template.position.angle or 0,
        ),
        effects=effects,
    )


def all_pins(symbol: Symbol):
    pins = list(symbol.pins)
    for unit in symbol.units:
        pins.extend(all_pins(unit))
    return pins


custom = SymbolLib.from_file(str(CUSTOM_LIB))
device = SymbolLib.from_file(str(KICAD_SYMBOLS / "Device.kicad_sym"))
power = SymbolLib.from_file(str(KICAD_SYMBOLS / "power.kicad_sym"))

source_symbols: dict[str, Symbol] = {}
for nickname, library in (("DockRev6", custom), ("Device", device), ("power", power)):
    for symbol in library.symbols:
        source_symbols[f"{nickname}:{symbol.entryName}"] = symbol


schematic = Schematic.create_new()
schematic.uuid = uid()
schematic.paper = PageSettings(paperSize="A4")
schematic.titleBlock = TitleBlock(
    title="OpenRemote Charging Dock Controller",
    date="2026-08-25",
    revision="6",
    company="OpenRemote",
    comments={1: "ESP32-C3 Super Mini + CC1101 + four-channel parallel IR emitter bank"},
)
schematic.sheetInstances = [HierarchicalSheetInstance(instancePath="/", page="1")]

embedded: set[str] = set()
placed: dict[str, tuple[SchematicSymbol, Symbol]] = {}


def add_symbol(
    lib_id: str,
    reference: str,
    value: str,
    x: float,
    y: float,
    footprint: str | None = None,
    datasheet: str | None = None,
    description: str | None = None,
) -> SchematicSymbol:
    x, y = snap(x), snap(y)
    source = source_symbols[lib_id]
    if lib_id not in embedded:
        embedded_symbol = deepcopy(source)
        embedded_symbol.libId = lib_id
        schematic.libSymbols.append(embedded_symbol)
        embedded.add(lib_id)

    defaults = {p.key: p.value for p in source.properties}
    footprint = defaults.get("Footprint", "") if footprint is None else footprint
    datasheet = defaults.get("Datasheet", "") if datasheet is None else datasheet
    description = defaults.get("Description", "") if description is None else description

    item = SchematicSymbol(
        position=Position(X=x, Y=y, angle=0),
        unit=1,
        inBom=not reference.startswith("#"),
        onBoard=not reference.startswith("#"),
        dnp=False,
        uuid=uid(),
    )
    item.libId = lib_id
    item.properties = [
        placed_property(source, "Reference", reference, x, y, reference.startswith("#")),
        placed_property(source, "Value", value, x, y, False),
        placed_property(source, "Footprint", footprint, x, y, True),
        placed_property(source, "Datasheet", datasheet, x, y, True),
        placed_property(source, "Description", description, x, y, True),
    ]
    for pin in all_pins(source):
        item.pins.setdefault(str(pin.number), uid())
    item.instances = [
        SymbolProjectInstance(
            name=PROJECT_NAME,
            paths=[SymbolProjectPath(sheetInstancePath="/", reference=reference, unit=1)],
        )
    ]
    schematic.schematicSymbols.append(item)
    placed[reference] = (item, source)
    return item


def pin_xy(reference: str, number: str) -> tuple[float, float, int]:
    item, source = placed[reference]
    pin = next(p for p in all_pins(source) if str(p.number) == str(number))
    return item.position.X + pin.position.X, item.position.Y - pin.position.Y, pin.position.angle or 0


def label_pin(reference: str, number: str, net: str) -> None:
    x, y, angle = pin_xy(reference, number)
    if angle == 0:
        target = Position(X=x - 7.62, Y=y)
        label_angle = 180
    elif angle == 180:
        target = Position(X=x + 7.62, Y=y)
        label_angle = 0
    else:
        # Turn vertical passive/power pins sideways so net labels stay readable.
        target = Position(X=x + 7.62, Y=y)
        label_angle = 0
    schematic.graphicalItems.append(
        Connection(
            type="wire",
            points=[Position(X=x, Y=y), target],
            stroke=Stroke(width=0),
            uuid=uid(),
        )
    )
    schematic.labels.append(
        LocalLabel(
            text=net,
            position=Position(X=target.X, Y=target.Y, angle=label_angle),
            effects=font_effects(),
            uuid=uid(),
        )
    )


def no_connect(reference: str, number: str) -> None:
    x, y, _ = pin_xy(reference, number)
    schematic.noConnects.append(NoConnect(position=Position(X=x, Y=y), uuid=uid()))


def heading(text: str, x: float, y: float) -> None:
    schematic.texts.append(
        Text(
            text=text,
            position=Position(X=x, Y=y, angle=0),
            effects=font_effects(size=1.8, bold=True),
            uuid=uid(),
        )
    )


def note(text: str, x: float, y: float) -> None:
    schematic.texts.append(
        Text(
            text=text,
            position=Position(X=x, Y=y, angle=0),
            effects=font_effects(size=1.27),
            uuid=uid(),
        )
    )
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

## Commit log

2026-08-04 Start Rev 6 Schematic
    [280QV10 v5.step, 541325062_colored.step, 82672Heimdall.stp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]
2026-08-04 Prepared to place mic on PCB
    [OpenRemote.kicad_pcb, OpenRemote.kicad_sch]
2026-08-04 Placed microphone on rear of PCB
    [OpenRemote.kicad_pcb]
2026-08-04 Routed microphone traces
    [OpenRemote.kicad_pcb]
2026-08-04 Organize PCB revision archives
    [280QV10 v5.step, 541325062_colored.step, 82672Heimdall.step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]
2026-08-04 Add headerless microphone 3D model
    [MS3625_Circular_Microphone_Module_No_Headers.step, OpenRemote.kicad_pcb]
2026-08-05 Update Rev 6 project metadata
    [OpenRemote.kicad_sch]
2026-08-07 Add Rev 6 microphone and display updates
    [ER-TFT028-4.2.step, ER-TFT028-4.2_Folded.step, Hirose_FH12-6S-0.5SH_1x06_P0.50mm.step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]
2026-08-23 Clear repository contents
    [280QV10 v5.step, 541325062_colored.step, 82672Heimdall.step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]
2026-08-23 Publish OpenRemote Rev6 PCB and hardware overview
    [280QV10 v5.step, 541325062_colored.step, 82672Heimdall.step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]
2026-08-23 Add J6 assembly part code
    [BOM.xlsx, OpenRemote.kicad_pcb, OpenRemote.kicad_sch]
2026-08-23 Fix Rev6 JLCPCB assembly files
    [BOM.xlsx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]
2026-08-27 Sync Rev 6 hardware work from workstation
    PCB (Revision 6):
    - J3 battery connector polarity update; the old KiBuzzard "(+)(-)"
    silkscreen graphic is replaced by a plain "Battery" F.Silkscreen label
    - J3 nudged 0.1 mm in X
    - Regenerated gerber.zip from the current board (kicad-cli 10.0.4)
    - U5 (LIS3DHTR) now marked DNP; C14/C27/U10 added as DNP
    - CPL.csv and BOM.xlsx left as-is pending regeneration
    Also adds previously unpublished work from the workstation: Case Rev6
    and Dock Rev6 CAD, Fusion scripts, PCB imports, Dock Rev6 board and
    scripts, and Rev6 render images.
    [Button Grid.stl, Button Grid_TPU.stl, CC1101_433MHz_Coil_Module.step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]
2026-08-27 Rev6 v27 - Includes charging pogo pins and front cover is 1mm thicker for the new LCD screen
2026-08-29 Merge MIC_VDD with IO45 net and regenerate Rev6 gerbers
    Schematic:
    - Added the missing 10.16 mm wire from (281.94, 69.85) to the MIC_VDD
    global label at (292.10, 69.85). The label had been drawn but never
    landed on the net, so MIC_VDD and Net-(D3-A) were two separate nets
    joined only by a track physically overlapping U7 pad 26 and D3 pad 2.
    - MIC_VDD now carries D3.2, MIC1.2 and U7.26 (IO45); Net-(D3-A) is gone.
    PCB:
    - Netlist re-imported; MIC1 pin 6 grounded via a track to a new GND via
    at (145.50, 104.50) landing in the B.Cu plane; MIC_VDD routed properly.
    - DRC errors 51 -> 44: all 4 shorting_items cleared, solder_mask_bridge
    9 -> 4 (remaining four are the fiducials).
    - Regener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
    [Case - Screws with Pogo Pins.stl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]
2026-08-29 Reposition Rev6 back-silkscreen refdes labels and regenerate gerbers
    Moved 8 reference/value fields on B.SilkS / B.Fab (LCD2, D13, D14, R42,
    R43 and others). No electrical change: track and via geometry is
    identical to the previous commit - 1521 segments and 355 vias, matching
    as sets.
    Regenerated gerber.zip. Normalising each layer to its aperture
    definitions and plot operations, F.Cu, B.Cu and F.Silkscreen are
    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
    [OpenRemote.kicad_pcb]
2026-08-29 Relocate J7 5V-in connector, reroute, and regenerate gerbers
    J7 moved from (214.000, 85.000, 90) to (218.500, 88.500, 90) - 4.5 mm
    right, 3.5 mm down - with its VUSB_RAW and GND routing redone and two
    GND vias relocated. A kibuzzard silkscreen label moved from
    (222.700, 85.200, 90) to (224.500, 84.000, 0).
    This clears both sub-spec clearances that were around J7:
    - J7 pad 1 (GND) to /VUSB_RAW was 0.1049 mm - gone
    - J7 pad MP to /VUSB_RAW was 0.1000 mm - gone
    DRC errors 44 -> 41, clearance violations 11 -> 8.
    Regenerated gerber.zip. Changed layers: F.Cu, B.Cu, F.Mask, F.Paste and
    both silkscreens. Mask (back), paste (back), edge cuts and both drill
    files are identical plots.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
    [OpenRemote.kicad_pcb]
2026-08-30 Shorten J6 touch connector silkscreen label and regenerate gerbers
    J6 value field on F.SilkS changed from "ER-CON06HB-1_TOUCH" to "Touch".
    No electrical change: 1519 track segments and 355 vias match the previous
    commit as sets, and no footprint moved.
    Regenerated gerber.zip. F.Silkscreen is the only layer that differs
    (-242 plot operations, consistent with the shorter string); F.Cu, B.Cu,
    both masks, both pastes, edge cuts, both drill files and the job file are
    identical plots.
    Also adds the v33 rear case STLs (pogo and no-pogo) and a read-only
    Fusion script, OpenRemoteRev6LipDiagnose, for tracing the missing
    outer-lip feature (Sketch39 / Extrude45).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
    [Case - Screws and No Pogo Pins v33.stl, Case - Screws with Pogo Pins v33.stl, OpenRemote.kicad_pcb]
2026-09-03 Restructure CAD around display variants, publish the Rev6 charging dock
    CAD is now organised by what you print rather than by revision:
    CAD/Adafruit LCD/ 3MF + STL set for the original Adafruit screen
    CAD/BuyDisplay LCD/ 3MF + STL set for the EastRising/BuyDisplay screen
    CAD/Dock/ dock shell, base lid, menu button + 3MF
    CAD/*.f3z current Fusion sources (remote v37/v38, dock v47)
    The old CAD/Case Rev6 and CAD/Dock Rev6 trees are gone; their current
    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
    [BOM.xlsx, Button Grid Adafruit Rev6-v37.stl, Button Grid BuyDisplay Rev6-v37.stl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]
2026-09-03 Explain why Rev6 moved to the BuyDisplay panel
    The README recommended the BuyDisplay screen without ever saying why.
    Adds a "Why the display changed" subsection giving the two reasons: the
    Adafruit Product 2770 / CH280QV10-CT is discontinued, and it is subject
    to a known ghost-touch fault, which on a remote control means the device
    wakes itself, fires unwanted commands at your equipment and drains its
    battery.
    Adds a matching subsection making clear the Adafruit panel remains a
    fully supported choice, because the Rev6 firmware has an option that
    runs it with zero ghost touches, plus short guidance on which panel to
    pick depending on whether you already own one.
    No setting name is given for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
2026-09-04 Update case and dock printed parts, add dock PCB fit-check model
    Printed parts:
    - Rear cases v37 -> v40, both variants, for both display builds
    - Dock shell and base lid v47 -> v51 (menu button stays at v47)
    - Adafruit and dock 3MF projects updated
    Fusion sources:
    - Remote: Rev6-v37 and Rev6-v38 consolidated into Rev6 v43
    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
    [Case - Screws and No Pogo Pins Rev6 v40.stl, Case - Screws and No Pogo Pins Rev6-v37.stl, Case - Screws with Pogo Pins Rev6 v40.stl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]
2026-09-07 Add the Rev 6 Dock product photo to the charging dock section
    Puts the dock banner where the section that describes it begins.
    Also adds a bullet explaining why the dock carries an ESP32-C3 at all: its
    own Wi-Fi lets it hold a permanent connection to Home Assistant, an MQTT
    broker or Homebridge and act while the remote sleeps. That is a firmware
    capability rather than a hardware one and is marked as such, with a link to
    the firmware repository - but it is the reason for the microcontroller, and
    the banner above it makes the claim, so the section should not leave it
    unexplained.
2026-09-07 Correct the dock power description: USB-C only
    The Charging dock section claimed the dock could be powered either
    through the ESP32-C3 module's USB-C or through the JST header J1. That
    is wrong. Power enters only via USB-C.
    J1 sits on the same +5V/GND rail, which is what made it look like a
    second input, but it is an output: it carries the 5 V rail out to the
    pogo pins that charge the remote.
2026-09-08 Rebuild dock BOM in the format JLCPCB accepts, drop the ESP32-C3
    JLCPCB rejected the dock BOM as too large to process. Size was not the
    problem - the file was 2.4 kB. It was a hand-built minimal xlsx: five
    zip entries using inline strings, with no sharedStrings.xml, styles.xml,
    theme or docProps. The remote BOM that JLCPCB accepts has sixteen.
    Rebuilt by cloning the remote BOM.xlsx and replacing only sheet1.xml and
    sharedStrings.xml, so the package structure is now byte-for-byte the
    same shape as the file that uploads cleanly - shared strings with t="s",
    styled header row, matching dimension and column widths.
    U1, the ESP32-C3 Super Mini, is removed from both BOM and CPL as an
    owner-fitted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
    [BOM.xlsx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]
2026-09-08 Restrict dock BOM and CPL to SMD parts only
    Both production files now cover only the parts JLCPCB's SMT service can
    place. Selection is driven by each footprint's own attr field rather
    than a hand-kept list, so it stays correct if the board changes.
    Kept, 12 parts in 8 grouped lines:
    C1,C3,C5,C7 100nF 0603 C1591
    C2,C4 10uF 0805 C15850
    D5 blue 0603 C965807
    Q1 FS8205A C908265
    R1 10k 0603 C98220
    R2 1k 0603 C22548
    R3 100R 0603 C125923
    R4 100k 0603 C25803
    Every remaining line has an LCSC code, so there are no gaps to resolve
    in the JLCPCB uploader.
    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
    [BOM.xlsx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]
2026-09-08 Withdraw dock fabrication files: ESP32-C3 footprint is wrong
    The ESP32-C3 Super Mini land pattern on the dock PCB is incorrect. The
    3D model is right, which is why this was not obvious, but a board made
    from the published files would not accept the module.
    Removed so nobody orders from them:
    PCB/Dock Rev6/Productions Files/gerber.zip
    PCB/Dock Rev6/Productions Files/CPL.csv
    PCB/Dock Rev6/Productions Files/BOM.xlsx
    The README no longer links to them and now says plainly not to order a
    dock PCB yet. Project status updated to match.
    The KiCad source stays published so the design can still be followed and
    reviewed. The remote's production files under PCB/Revision 6 are
    untouched - that b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
    [BOM.xlsx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]
2026-09-09 Tidy the dock project and add D6 pogo-output protection diode
    Cleanup - removed 21 files, keeping only the current board and
    schematic. Everything remains in git history for rollback:
    - 14 Dock Rev6.before-* rollback boards, schematics and prl
    - Dock Rev6 Component Staging Backup.kicad_pcb
    - 4 DRC/ERC/parity report files
    - Dock Rev6.net and the exported Dock Rev6 Schematic.pdf
    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
    [D_SOD-323.step, Dock Rev6 Component Staging Backup.kicad_pcb, Dock Rev6.before-c2837541-switch.kicad_pcb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]
2026-09-09 Replace the pogo diode with a 1A polyfuse
    D6, the BAT20J Schottky added in the previous commit, is dropped in
    favour of F1, a 1 A resettable polyfuse - the same part the remote uses
    as its F1 (Device:Polyfuse, 1000mA, LCSC C220146).
    It sits in the same place, in series between +5V and J1 pin 1 on the
    POGO_5V net, with the IR bank, ESP32 and decoupling still on the raw 5V
    rail. Still schematic only; not placed on the PCB.
    Better suited to the job on both counts. A polyfuse trips on a shorted
    pogo pair, which is the failure actually being guarded against and which
    a series diode does nothing about. And it drops tens of millivolts
    rather than roughly 0.45 V at 1 A, so the remote sees close to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
    [D_SOD-323.step, Dock Rev6.kicad_sch, Fuse_1206_3216Metric.step]

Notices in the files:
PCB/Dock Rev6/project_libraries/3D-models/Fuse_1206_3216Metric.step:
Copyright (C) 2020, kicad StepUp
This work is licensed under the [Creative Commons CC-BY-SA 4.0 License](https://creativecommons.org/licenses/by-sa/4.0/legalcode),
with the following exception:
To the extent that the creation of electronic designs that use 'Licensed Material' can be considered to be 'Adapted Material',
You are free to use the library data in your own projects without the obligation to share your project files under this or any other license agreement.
